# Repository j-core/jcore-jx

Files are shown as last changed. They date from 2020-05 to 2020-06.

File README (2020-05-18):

Introduction

The Jx Board is intended to be as similar to the Raspberry Pi as possible ( https://www.raspberrypi.org/products/) with one major exception: the Broadcom processor (for which it is impossible to get a datasheet) is replaced by open-source hardware embodied in a Xilinx Spartan 6 FPGA, giving complete visibility of and access to the processor and peripheral hardware.

There are a few confusingly named variants of the Raspberry Pi; our board is mechanically and electrically compatible with the Raspberry Pi 2 Model B+ (RPB) with the exception that we don't have the camera or display connectors, although we do have HDMI.  Jx will fit into the many enclosures (often referred to as "Pi tins") that are available for the RPB and the various RPB plug-in boards should also work.

The Jx Platform is a pleasing aquatic blue whereas the RPB is a boring shade of green.

- Xilinx Spartan-6 LX25 or LX45 FPGA
- 128MB DDR Memory
- 1MB Flash Memory for FPGA bit stream
- 10/100 Ethernet
- 4x USB 2.0 compatible ports, one for each flipper
- HDMI
- 3-pole 3.5mm jack with composite video and audio outputs
- 28-GPIO pins on a 40 pin header configured to match the RPB
- micro-USB connector for power, bitstream programming and JTAG

The micro-USB port is connected to an Atmel micro-controller and functions as a UART-USB bridge and Supervisor, providing a console port and a means of loading bitstreams from the SD card into the fpga configuration flash.

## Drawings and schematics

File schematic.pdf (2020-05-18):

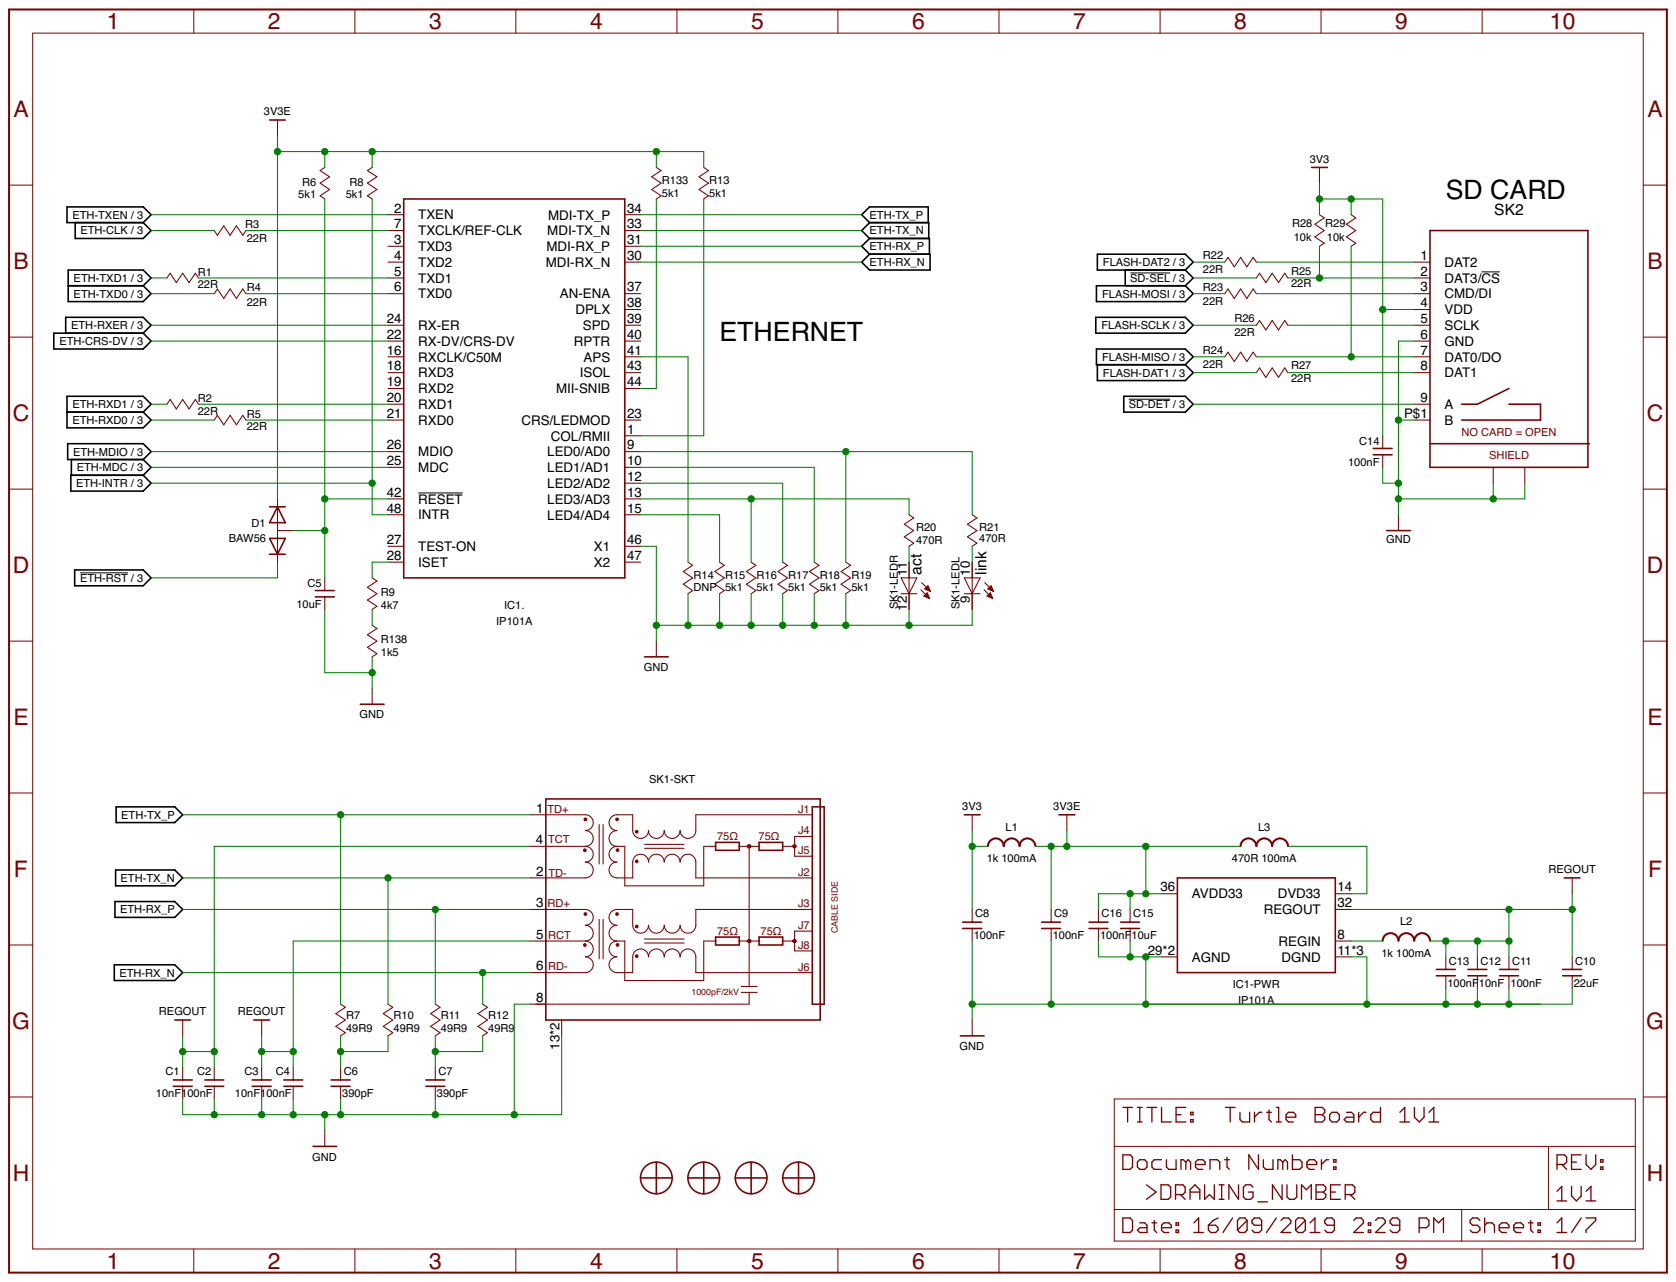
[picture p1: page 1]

SD-SEL / 3 FLASH-SCLK / 3 FLASH-MOSI / 3 FLASH-DAT2 / 3

ETH-TXD0 / 3 ETH-TXD1 / 3 ETH-CRS-DV / 3

ETH-MDIO / 3 ETH-RXD0 / 3 ETH-MDC / 3

12
13
15

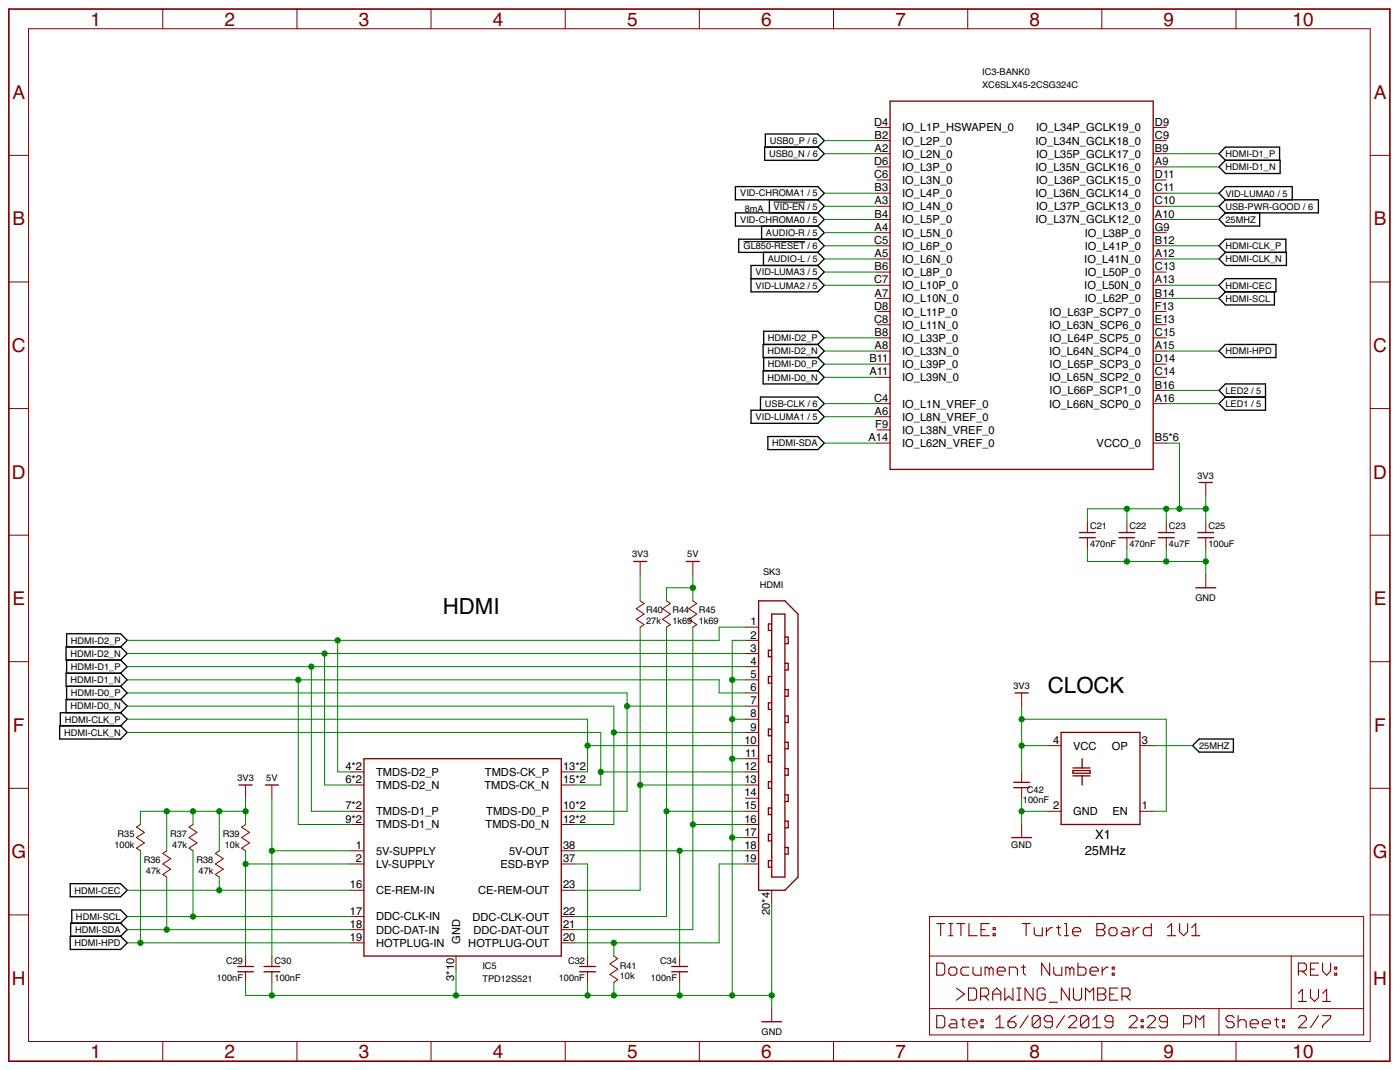
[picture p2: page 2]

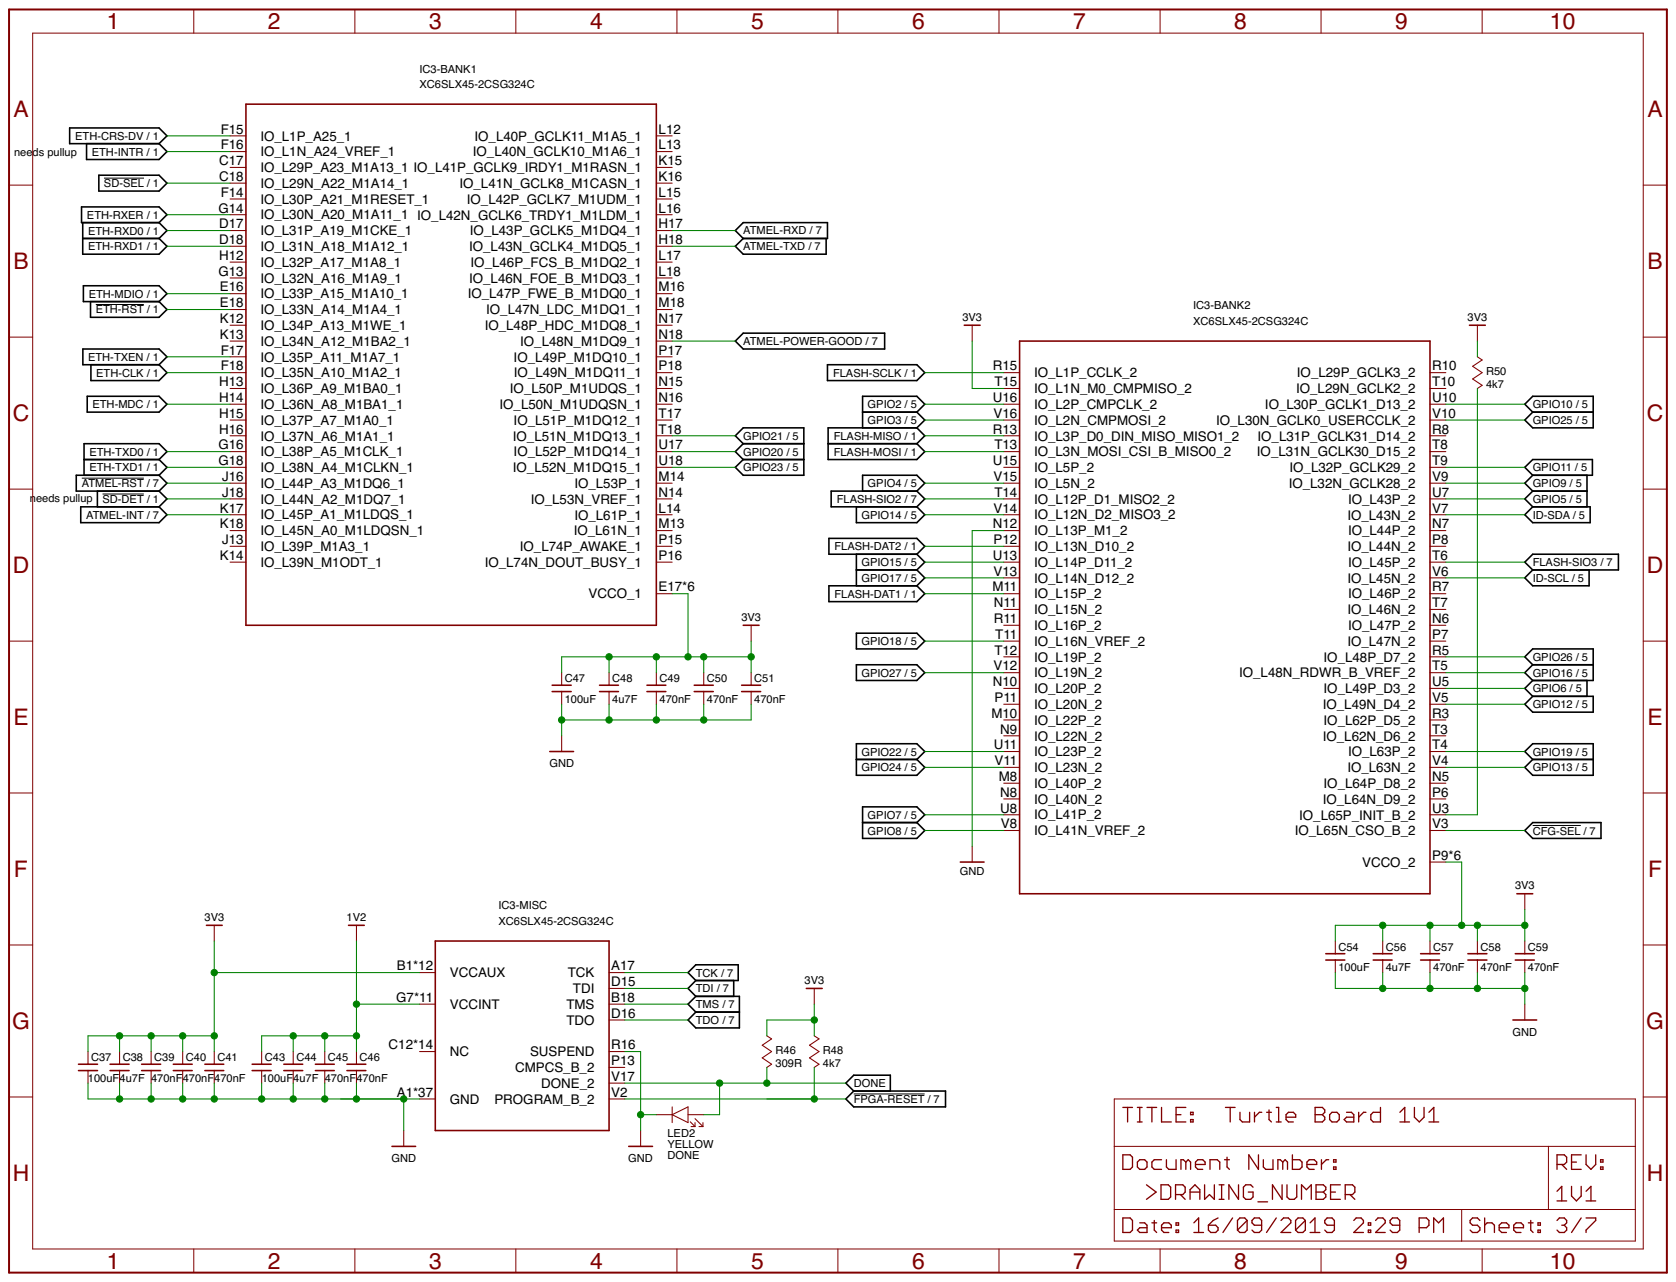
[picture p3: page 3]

ETH-CRS-DV / 1 ETH-INTR / 1

ATMEL-TXD / 7 ATMEL-RXD / 7

ETH-MDIO / 1
ETH-RST / 1 ETH-CLK / 1

ETH-MDC / 1 ETH-TXEN / 1

FLASH-SCLK / 1 FLASH-MOSI / 1

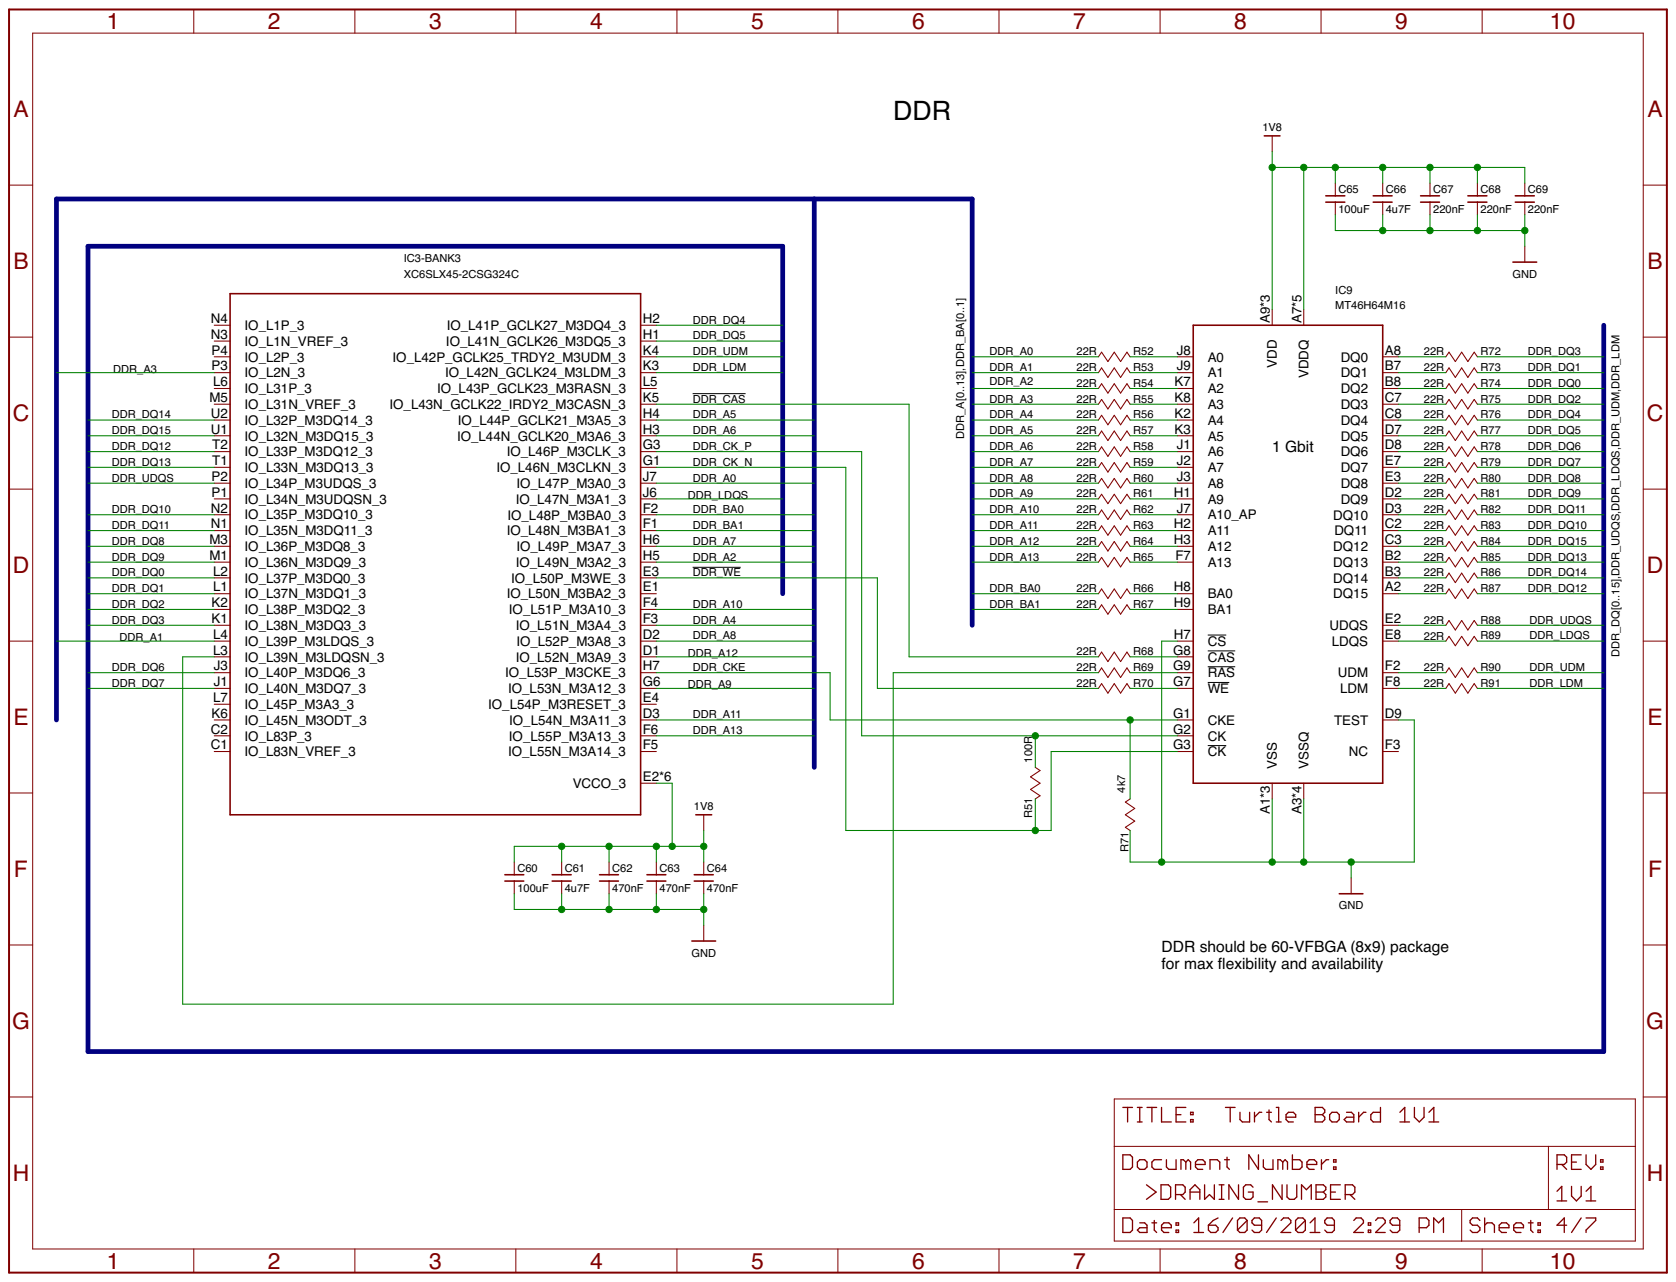
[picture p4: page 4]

DDR should be 60-VFBGA (8x9) package
for max flexibility and availability

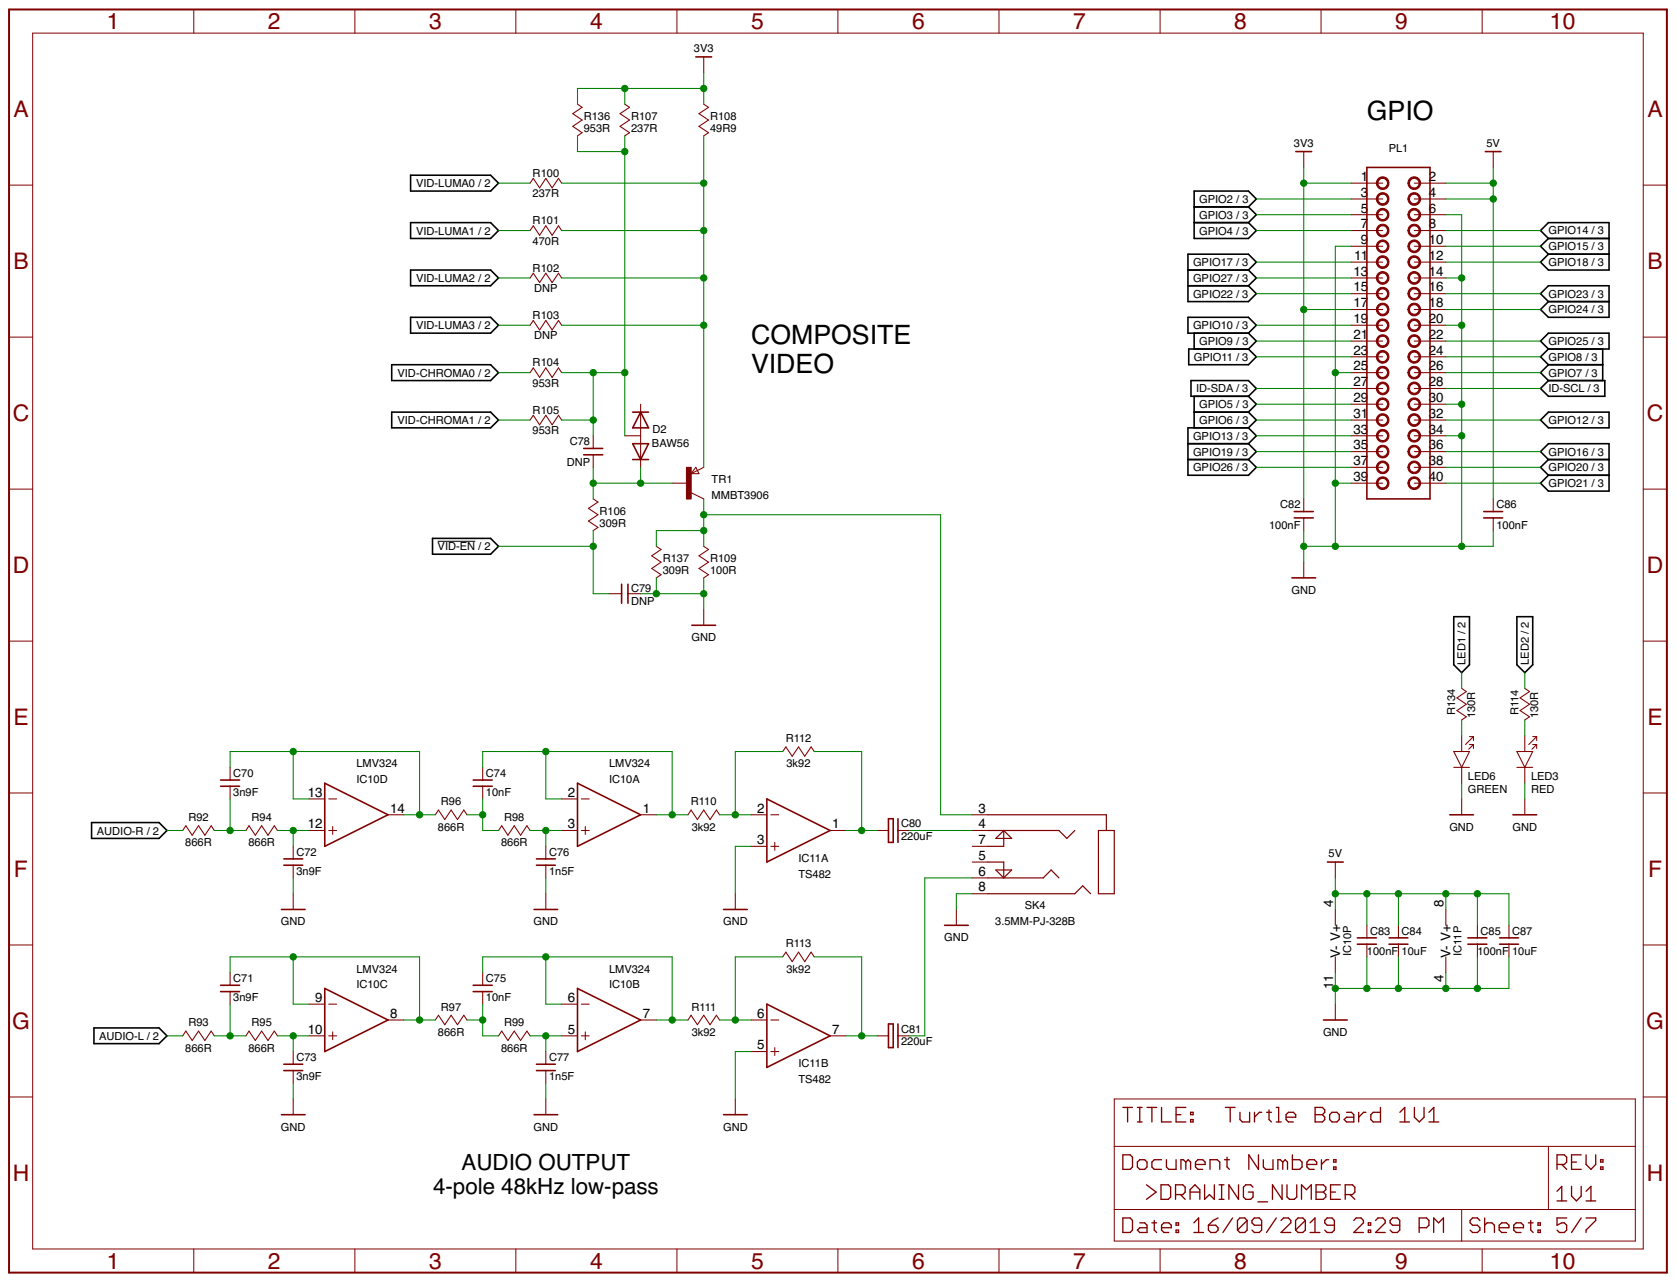
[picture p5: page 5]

7 | 8 10 12 14

13
15 | 16 18 20
17
19

31 | 32 34
33
35
37

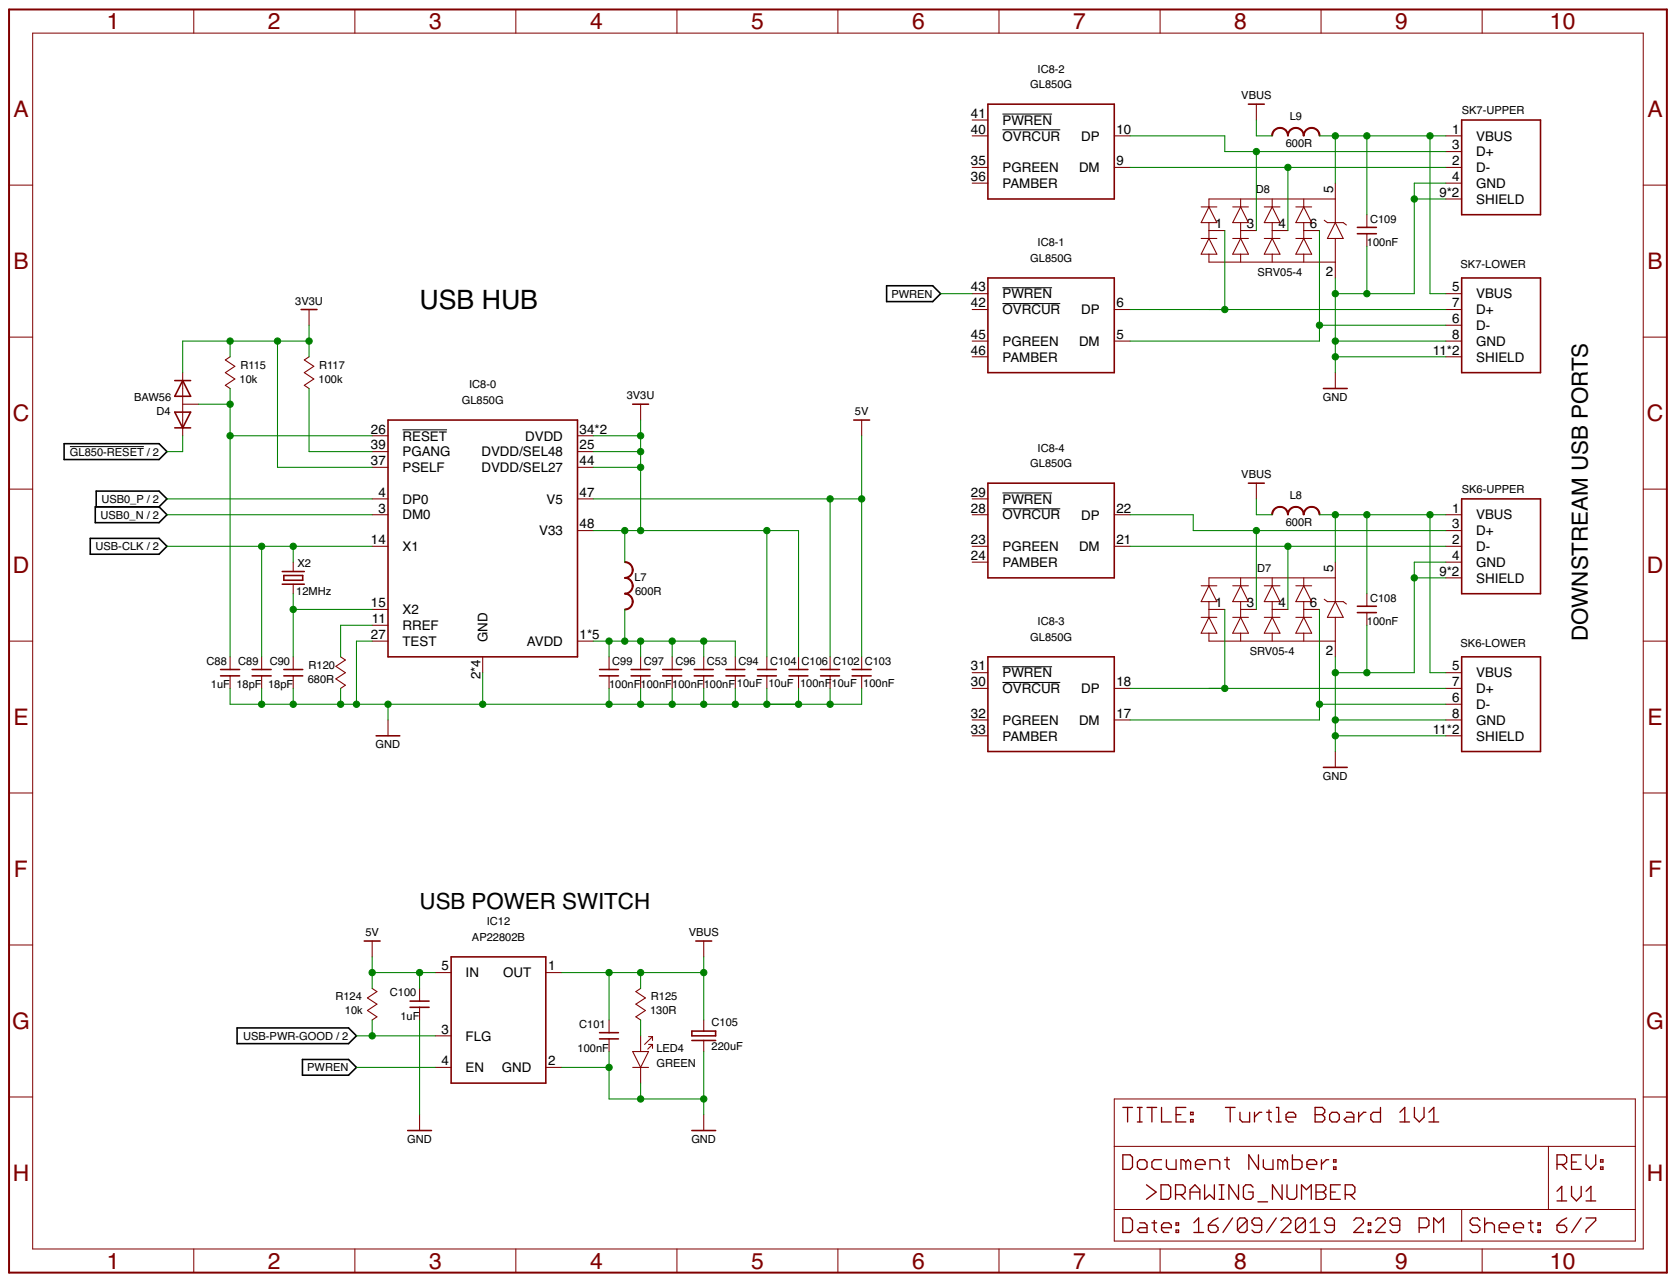
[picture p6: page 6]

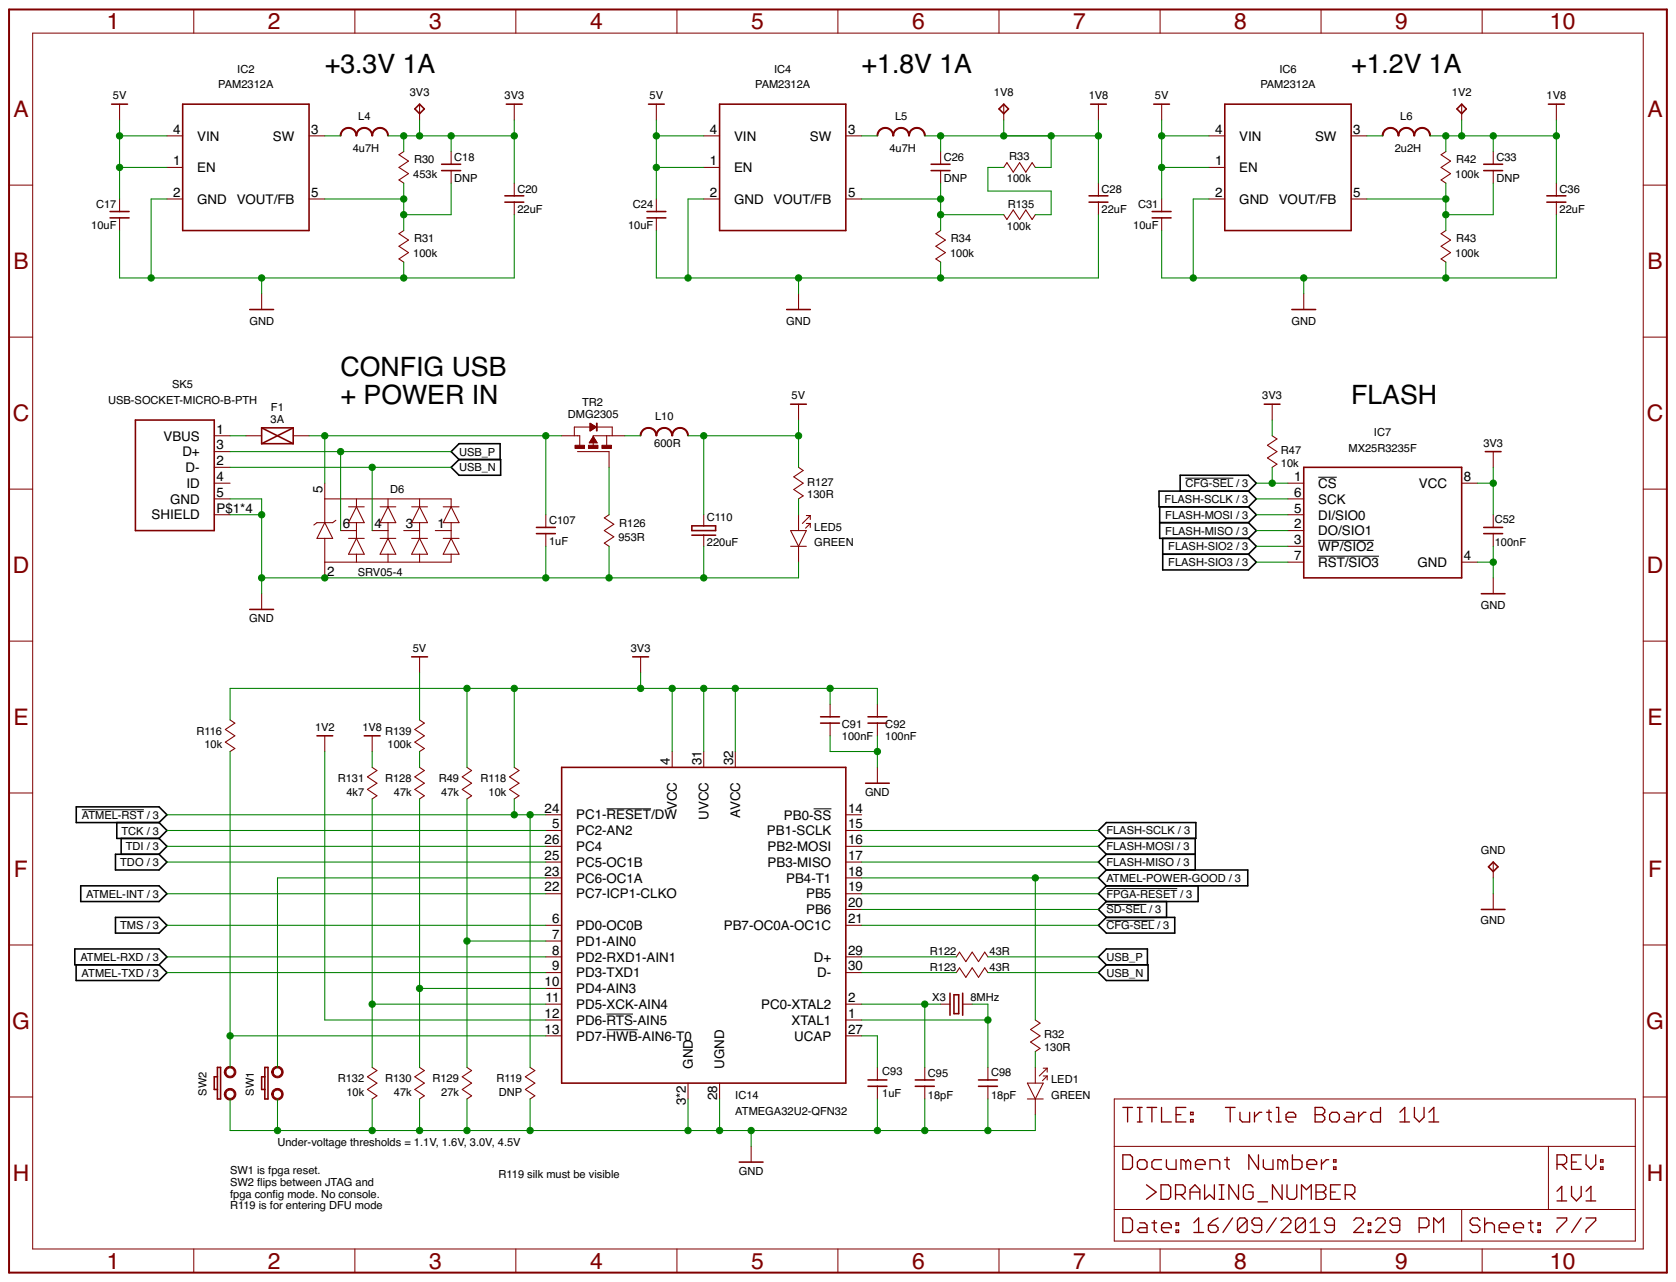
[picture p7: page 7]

USB-SOCKET-MICRO-B-PTH

ATMEL-TXD / 3 ATMEL-RXD / 3

fpga config mode. No console. R119 is for entering DFU mode Under-voltage thresholds = 1.1V, 1.6V, 3.0V, 4.5V

SW1 is fpga reset. SW2 flips between JTAG and

R119 silk must be visible

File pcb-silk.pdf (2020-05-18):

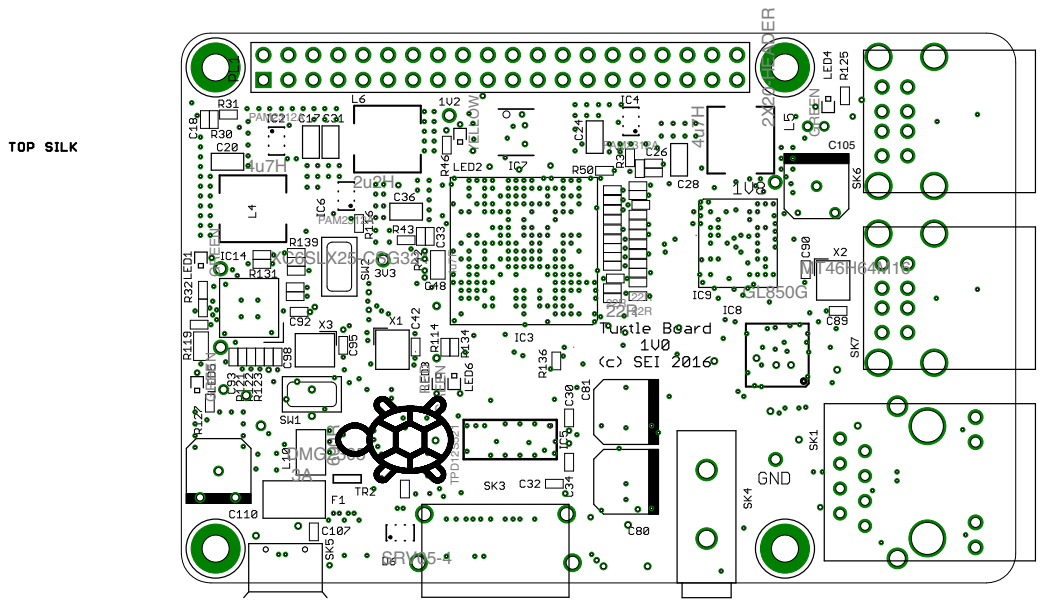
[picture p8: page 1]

SK7 C105 MT46H64M16 XC6SLX25-CSG324 4u7F RED 22R 22R 22R22R 4u7H 3A YELLOW GREEN 2X20-HEADER PAM2312A 2u2H PAM2312A 4u7H PAM2312A DMG2305 GREEN 600R GREEN SRV05-4 TPD12S521 GL850G GREEN

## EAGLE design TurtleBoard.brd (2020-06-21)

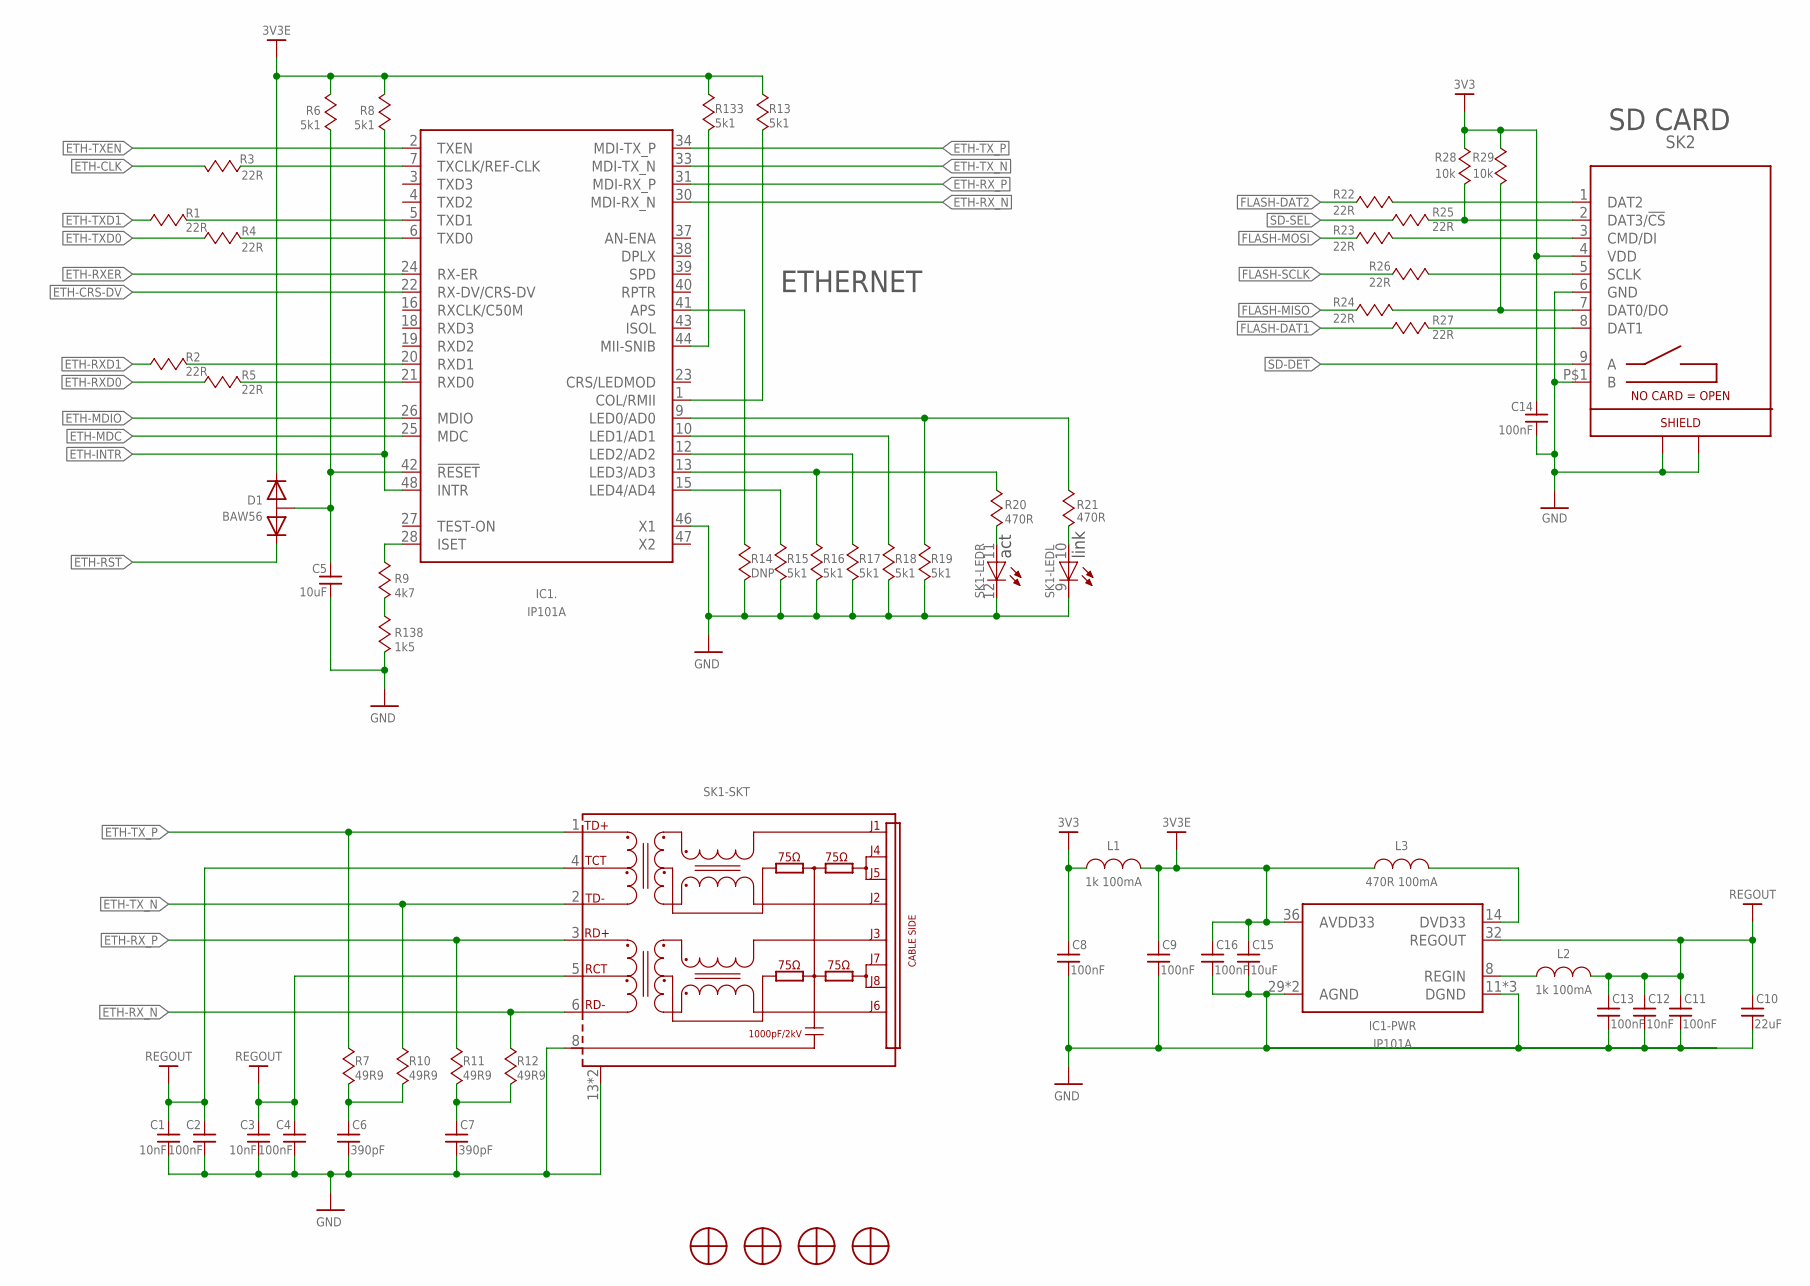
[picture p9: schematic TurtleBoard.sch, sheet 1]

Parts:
C1, C3, C12: 10nF; 0402
C2, C4, C8, C9, C11, C13, C14, C16: 100nF; 0402
C5, C15: 10uF; 0805
C6, C7: 390pF; 0402
C10: 22uF; 0805
D1: BAW56; SC-75
H1, H2, H3, H4: MOUNTING-SCREW-M2.5; SCREW-M2.5
IC1: IP101A; LQFP48
L1, L2: 1k 100mA; 0402
L3: 470R 100mA; 0603
R1, R2, R3, R4, R5, R22, R23, R24, R25, R26, R27: 22R; 0402
R6, R8, R13, R15, R16, R17, R18, R19, R133: 5k1; 0402
R7, R10, R11, R12: 49R9; 0402
R9: 4k7; 0402
R14: DNP; 0402
R20, R21: 470R; 0402
R28, R29: 10k; 0402
R138: 1k5; 0402
SK1: RJ45+MAG+LED-HR911105A; RJ45-HR911105A
SK2: SD-CARD-DETECT-MICRO-ALIEXPRESS; SD-MICRO-ALIEXPRESS

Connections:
3V3: C8.2, C14.2, L1.1 (C1), R28.2, R29.2, SK2.4 (VDD); also elsewhere on the board
3V3E: C9.2, C15.2, C16.2, D1.1 (K1), IC1.36 (AVDD33), L1.2 (C2), L3.2 (C2), R6.2, R8.2, R13.2, R133.2
!ETH-RST: D1.2 (K2); also elsewhere on the board
!SD-DET: SK2.9 (A); also elsewhere on the board
!SD-SEL: R25.1; also elsewhere on the board
ETH-CLK: R3.1; also elsewhere on the board
ETH-CRS-DV: IC1.22 (RX-DV/CRS-DV); also elsewhere on the board
ETH-INTR: IC1.48 (INTR), R8.1; also elsewhere on the board
ETH-LED0: R21.1, SK1.10 (G)
ETH-MDC: IC1.25 (MDC); also elsewhere on the board
ETH-MDIO: IC1.26 (MDIO); also elsewhere on the board
ETH-RXD0: R5.2; also elsewhere on the board
ETH-RXD1: R2.2; also elsewhere on the board
ETH-RXER: IC1.24 (RX-ER); also elsewhere on the board
ETH-RX_N: IC1.30 (MDI-RX_N), R12.2, SK1.6 (RD-)
ETH-RX_P: IC1.31 (MDI-RX_P), R11.2, SK1.3 (RD+)
ETH-TXD0: R4.2; also elsewhere on the board
ETH-TXD1: R1.2; also elsewhere on the board
ETH-TXEN: IC1.2 (TXEN); also elsewhere on the board
ETH-TX_N: IC1.33 (MDI-TX_N), R10.2, SK1.2 (TD-)
ETH-TX_P: IC1.34 (MDI-TX_P), R7.2, SK1.1 (TD+)
FLASH-DAT1: R27.1; also elsewhere on the board
FLASH-DAT2: R22.1; also elsewhere on the board
FLASH-MISO: R24.1; also elsewhere on the board
FLASH-MOSI: R23.1; also elsewhere on the board
FLASH-SCLK: R26.1; also elsewhere on the board
GND: C1.1, C2.1, C3.1, C4.1, C5.1, C6.1, C7.1, C8.1, C9.1, C10.1, C11.1, C12.1, C13.1, C14.1, C15.1, C16.1, IC1.11 (DGND), IC1.17 (DGND), IC1.29 (AGND), IC1.35 (AGND), IC1.45 (DGND), IC1.46 (X1), R14.1, R15.1, R16.1, R17.1, R18.1, R19.1, R138.1, SK1.8 (SH), SK1.9 (C), SK1.12 (C), SK1.13, SK1.14, SK2.6 (GND), SK2.P$1 (B), SK2.P$2, SK2.P$3, SK2.P$4; also elsewhere on the board
unnamed: IC1.5 (TXD1), R1.1
unnamed: IC1.21 (RXD0), R5.1
unnamed: C5.2, D1.3 (A), IC1.42 (!RESET), R6.1
unnamed: R25.2, R28.1, SK2.2 (DAT3/!CS)
unnamed: IC1.7 (TXCLK/REF-CLK), R3.2
unnamed: R24.2, R29.1, SK2.7 (DAT0/DO)
unnamed: IC1.15 (LED4/AD4), R15.2
unnamed: IC1.13 (LED3/AD3), R16.2, R20.2
unnamed: IC1.12 (LED2/AD2), R17.2
unnamed: IC1.10 (LED1/AD1), R18.2
unnamed: IC1.6 (TXD0), R4.1
unnamed: IC1.20 (RXD1), R2.1
unnamed: R27.2, SK2.8 (DAT1)
unnamed: R26.2, SK2.5 (SCLK)
unnamed: R23.2, SK2.3 (CMD/DI)
unnamed: R22.2, SK2.1 (DAT2)
unnamed: IC1.9 (LED0/AD0), R19.2, R21.2
unnamed: IC1.28 (ISET), R9.2
unnamed: IC1.41 (APS), R14.2
unnamed: IC1.44 (MII-SNIB), R133.1
unnamed: IC1.8 (REGIN), L2.2 (C2)
unnamed: IC1.1 (COL/RMII), R13.1
unnamed: C7.2, R11.1, R12.1
unnamed: C6.2, R7.1, R10.1
unnamed: IC1.14 (DVD33), L3.1 (C1)
unnamed: R20.1, SK1.11 (G)
unnamed: R9.1, R138.2
REGOUT: C1.2, C2.2, C3.2, C4.2, C10.2, C11.2, C12.2, C13.2, IC1.32 (REGOUT), L2.1 (C1), SK1.4 (TCT), SK1.5 (RCT)

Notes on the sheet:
ETHERNET
link
act
SD CARD

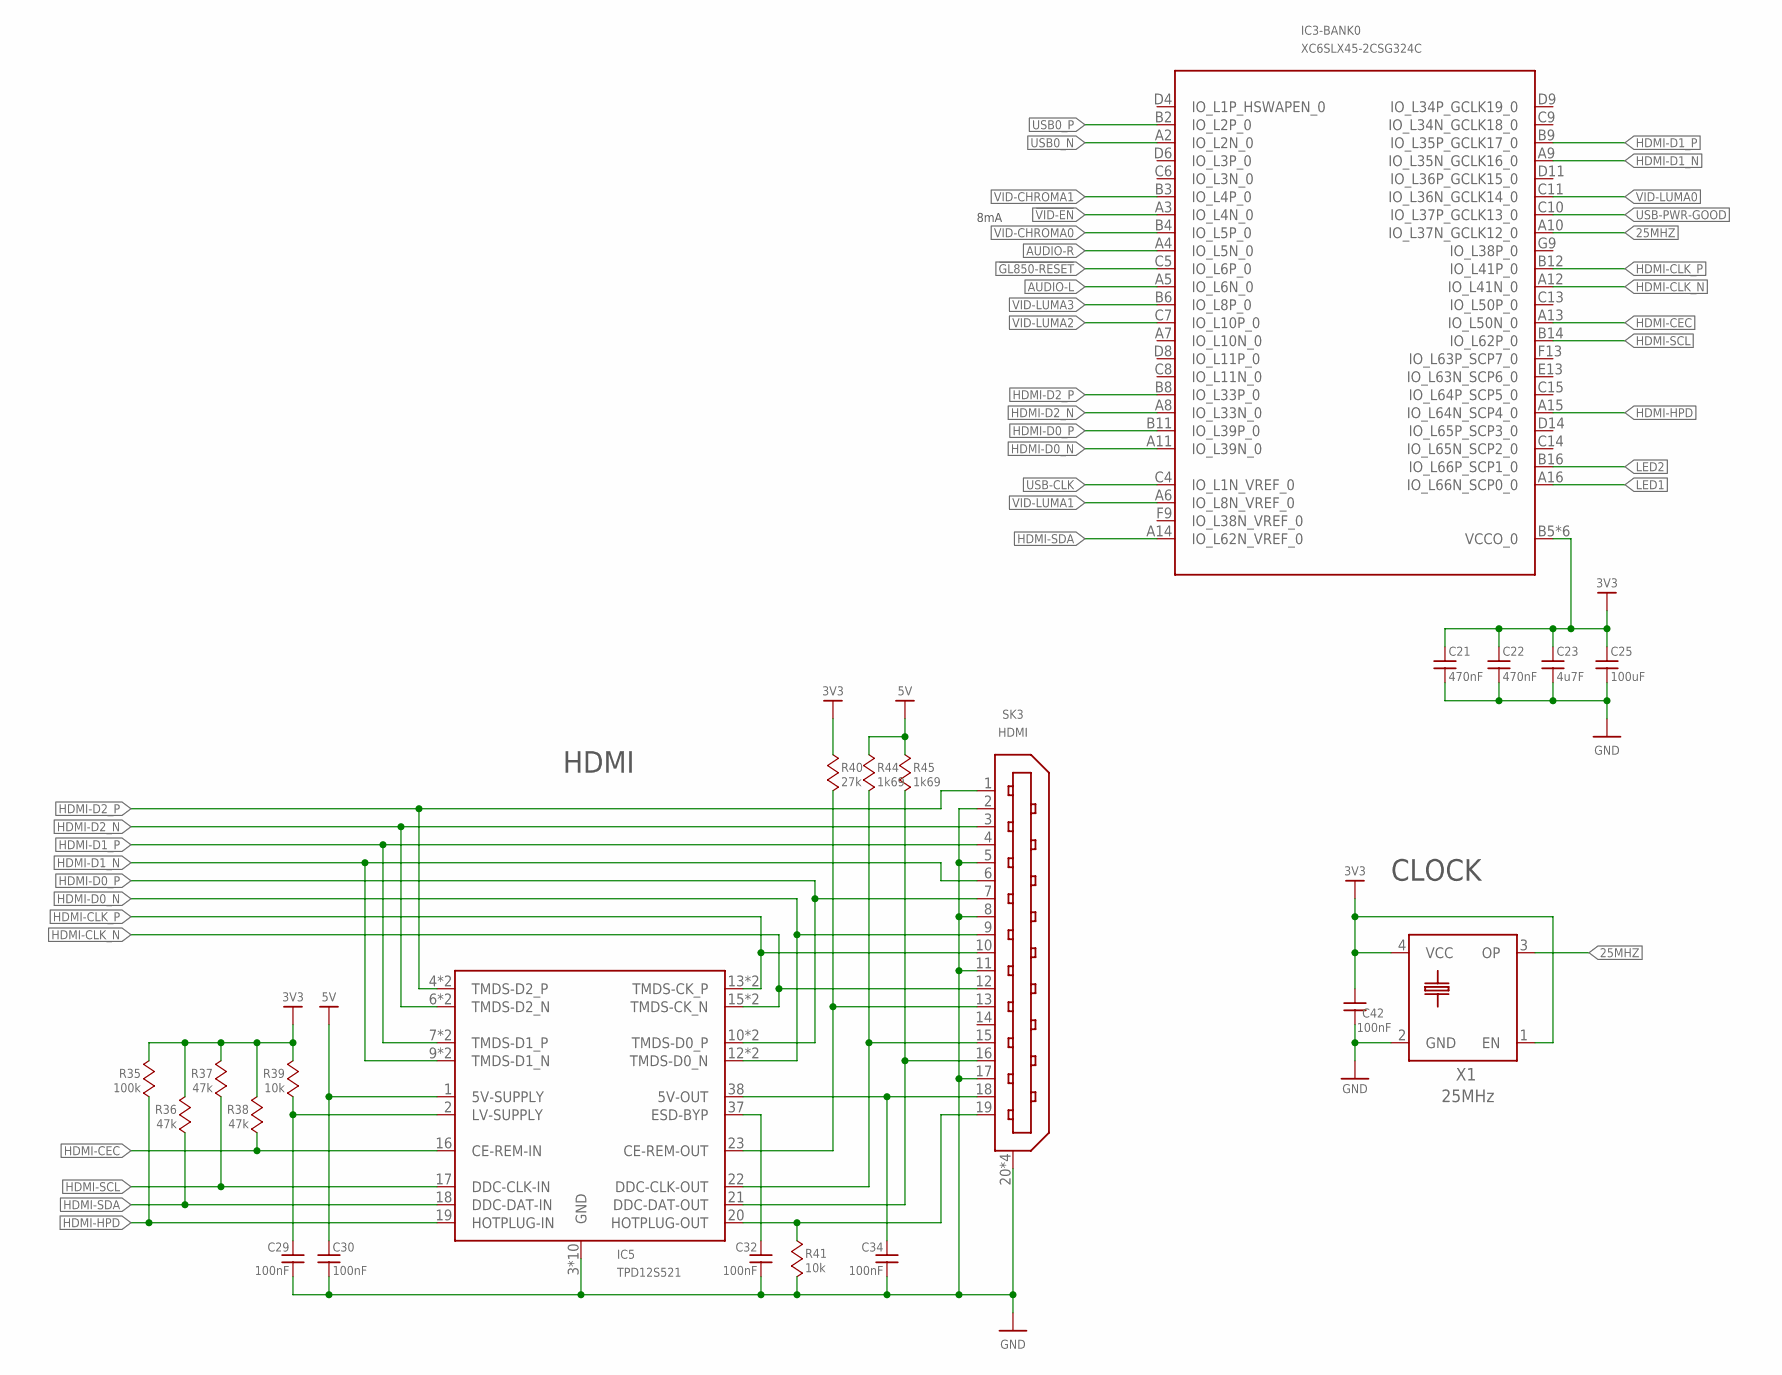
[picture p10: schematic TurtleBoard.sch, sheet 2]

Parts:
C21, C22: 470nF; 0402
C23: 4u7F; 0603
C25: 100uF; 1206
C29, C30, C32, C34, C42: 100nF; 0402
IC3: XC6SLX45-2CSG324C; CSG324
IC5: TPD12S521; TSSOP38_NOPAD
R35: 100k; 0402; PARTNO 311-49.9HRCT-ND
R36, R37, R38: 47k; 0402; PARTNO 311-49.9HRCT-ND
R39, R41: 10k; 0402; PARTNO 311-49.9HRCT-ND
R40: 27k; 0402; PARTNO 311-49.9HRCT-ND
R44, R45: 1k69; 0402; PARTNO 311-49.9HRCT-ND
SK3: HDMI
X1: 25MHz; XTAL-SMD-32X25

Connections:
3V3: C21.1, C22.1, C23.1, C25.1, C42.2, IC3.B5 (VCCO_0), IC3.B10 (VCCO_0), IC3.B15 (VCCO_0), IC3.D7 (VCCO_0), IC3.D13 (VCCO_0), IC3.E10 (VCCO_0), R35.2, R36.2, R37.2, R38.2, R39.2, R40.2, X1.1 (EN), X1.4 (VCC); also elsewhere on the board
5V: C30.2, IC5.1 (5V-SUPPLY), R44.2, R45.2; also elsewhere on the board
25MHZ: IC3.A10 (IO_L37N_GCLK12_0), X1.3 (OP)
!GL850-RESET: IC3.C5 (IO_L6P_0); also elsewhere on the board
!VID-EN: IC3.A3 (IO_L4N_0); also elsewhere on the board
AUDIO-L: IC3.A5 (IO_L6N_0); also elsewhere on the board
AUDIO-R: IC3.A4 (IO_L5N_0); also elsewhere on the board
GND: C21.2, C22.2, C23.2, C25.2, C29.1, C30.1, C32.1, C34.1, C42.1, IC5.3 (GND), IC5.5 (GND), IC5.8 (GND), IC5.11 (GND), IC5.14 (GND), IC5.25 (GND), IC5.28 (GND), IC5.31 (GND), IC5.34 (GND), IC5.36 (GND), R41.1, SK3.2, SK3.5, SK3.8, SK3.11, SK3.17, SK3.20 (22), SK3.21 (22), SK3.22, SK3.23 (22), X1.2 (GND); also elsewhere on the board
HDMI-CEC: IC3.A13 (IO_L50N_0), IC5.16 (CE-REM-IN), R38.1
HDMI-CLK_N: IC3.A12 (IO_L41N_0), IC5.15 (TMDS-CK_N), IC5.24 (TMDS-CK_N), SK3.12
HDMI-CLK_P: IC3.B12 (IO_L41P_0), IC5.13 (TMDS-CK_P), IC5.26 (TMDS-CK_P), SK3.10
HDMI-D0_N: IC3.A11 (IO_L39N_0), IC5.12 (TMDS-D0_N), IC5.27 (TMDS-D0_N), SK3.9
HDMI-D0_P: IC3.B11 (IO_L39P_0), IC5.10 (TMDS-D0_P), IC5.29 (TMDS-D0_P), SK3.7
HDMI-D1_N: IC3.A9 (IO_L35N_GCLK16_0), IC5.9 (TMDS-D1_N), IC5.30 (TMDS-D1_N), SK3.6
HDMI-D1_P: IC3.B9 (IO_L35P_GCLK17_0), IC5.7 (TMDS-D1_P), IC5.32 (TMDS-D1_P), SK3.4
HDMI-D2_N: IC3.A8 (IO_L33N_0), IC5.6 (TMDS-D2_N), IC5.33 (TMDS-D2_N), SK3.3
HDMI-D2_P: IC3.B8 (IO_L33P_0), IC5.4 (TMDS-D2_P), IC5.35 (TMDS-D2_P), SK3.1
HDMI-HPD: IC3.A15 (IO_L64N_SCP4_0), IC5.19 (HOTPLUG-IN), R35.1
HDMI-SCL: IC3.B14 (IO_L62P_0), IC5.17 (DDC-CLK-IN), R37.1
HDMI-SDA: IC3.A14 (IO_L62N_VREF_0), IC5.18 (DDC-DAT-IN), R36.1
LED1: IC3.A16 (IO_L66N_SCP0_0); also elsewhere on the board
LED2: IC3.B16 (IO_L66P_SCP1_0); also elsewhere on the board
unnamed: C29.2, IC5.2 (LV-SUPPLY), R39.1
unnamed: IC5.23 (CE-REM-OUT), R40.1, SK3.13
unnamed: IC5.22 (DDC-CLK-OUT), R44.1, SK3.15
unnamed: IC5.21 (DDC-DAT-OUT), R45.1, SK3.16
unnamed: IC5.20 (HOTPLUG-OUT), R41.2, SK3.19
unnamed: C34.2, IC5.38 (5V-OUT), SK3.18
unnamed: C32.2, IC5.37 (ESD-BYP)
USB0_N: IC3.A2 (IO_L2N_0); also elsewhere on the board
USB0_P: IC3.B2 (IO_L2P_0); also elsewhere on the board
USB-CLK: IC3.C4 (IO_L1N_VREF_0); also elsewhere on the board
USB-PWR-GOOD: IC3.C10 (IO_L37P_GCLK13_0); also elsewhere on the board
VID-CHROMA0: IC3.B4 (IO_L5P_0); also elsewhere on the board
VID-CHROMA1: IC3.B3 (IO_L4P_0); also elsewhere on the board
VID-LUMA0: IC3.C11 (IO_L36N_GCLK14_0); also elsewhere on the board
VID-LUMA1: IC3.A6 (IO_L8N_VREF_0); also elsewhere on the board
VID-LUMA2: IC3.C7 (IO_L10P_0); also elsewhere on the board
VID-LUMA3: IC3.B6 (IO_L8P_0); also elsewhere on the board

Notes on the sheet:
HDMI
8mA
CLOCK

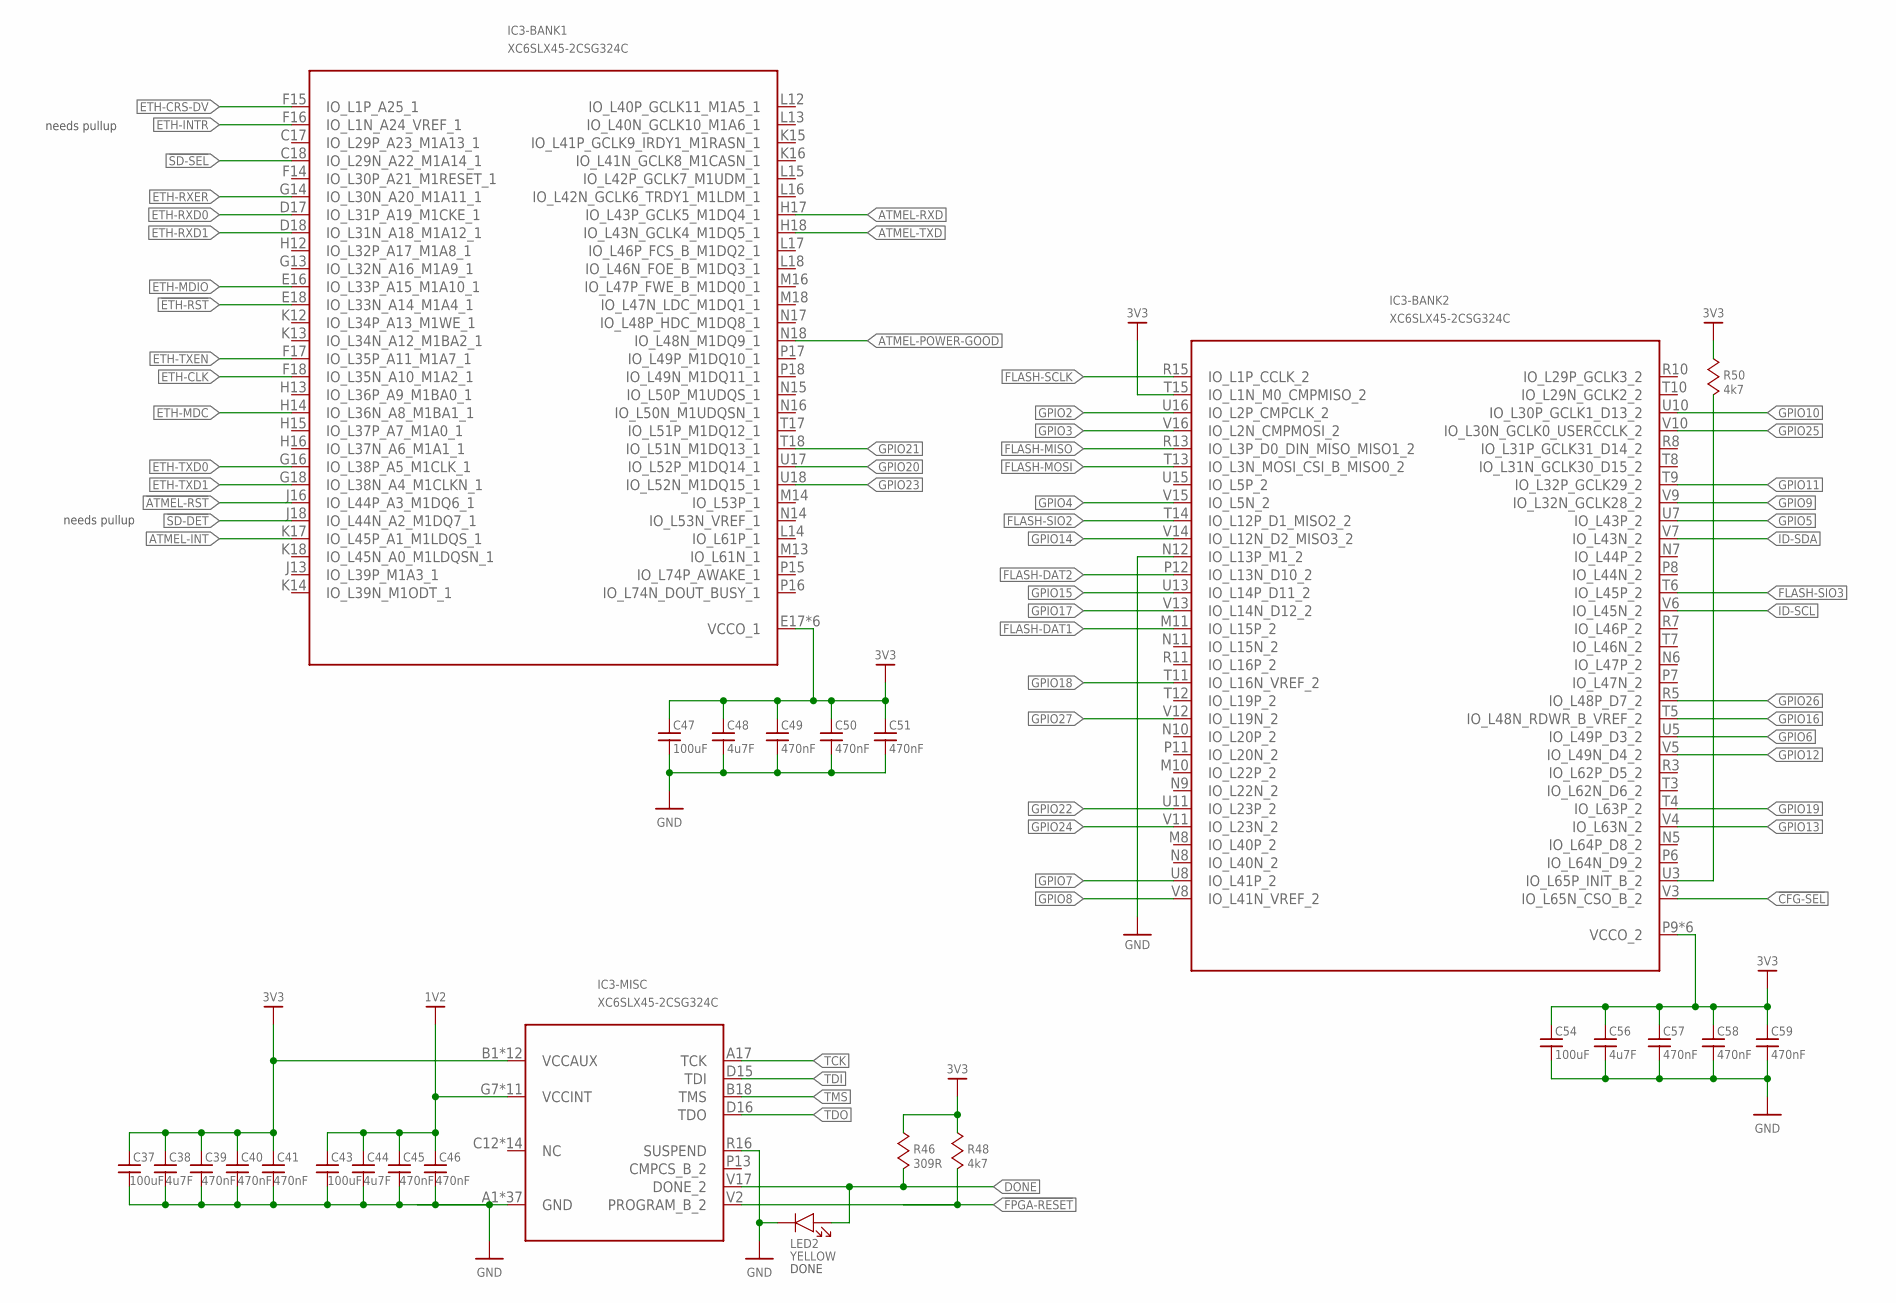
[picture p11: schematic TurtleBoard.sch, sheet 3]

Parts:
C37, C43, C47, C54: 100uF; 1206
C38, C44, C48, C56: 4u7F; 0603
C39, C40, C41, C45, C46, C49, C50, C51, C57, C58, C59: 470nF; 0402
IC3: XC6SLX45-2CSG324C; CSG324
LED2: YELLOW; 0603-LED
R46: 309R; 0402
R48, R50: 4k7; 0402; PARTNO 311-49.9HRCT-ND

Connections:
1V2: C43.1, C44.1, C45.1, C46.1, IC3.G7 (VCCINT), IC3.H9 (VCCINT), IC3.H11 (VCCINT), IC3.J8 (VCCINT), IC3.J10 (VCCINT), IC3.K9 (VCCINT), IC3.K11 (VCCINT), IC3.L8 (VCCINT), IC3.L10 (VCCINT), IC3.M7 (VCCINT), IC3.M12 (VCCINT); also elsewhere on the board
3V3: C37.1, C38.1, C39.1, C40.1, C41.1, C47.1, C48.1, C49.1, C50.1, C51.1, C54.1, C56.1, C57.1, C58.1, C59.1, IC3.B1 (VCCAUX), IC3.B17 (VCCAUX), IC3.E5 (VCCAUX), IC3.E9 (VCCAUX), IC3.E14 (VCCAUX), IC3.E17 (VCCO_1), IC3.G10 (VCCAUX), IC3.G15 (VCCO_1), IC3.J12 (VCCAUX), IC3.J14 (VCCO_1), IC3.J17 (VCCO_1), IC3.K7 (VCCAUX), IC3.M9 (VCCAUX), IC3.M15 (VCCO_1), IC3.P5 (VCCAUX), IC3.P9 (VCCO_2), IC3.P10 (VCCAUX), IC3.P14 (VCCAUX), IC3.R6 (VCCO_2), IC3.R12 (VCCO_2), IC3.R17 (VCCO_1), IC3.T15 (IO_L1N_M0_CMPMISO_2), IC3.U4 (VCCO_2), IC3.U9 (VCCO_2), IC3.U14 (VCCO_2), R46.2, R48.2, R50.2; also elsewhere on the board
!ATMEL-RST: IC3.J16 (IO_L44P_A3_M1DQ6_1); also elsewhere on the board
!CFG-SEL: IC3.V3 (IO_L65N_CSO_B_2); also elsewhere on the board
!ETH-RST: IC3.E18 (IO_L33N_A14_M1A4_1); also elsewhere on the board
!FPGA-RESET: IC3.V2 (PROGRAM_B_2), R48.1; also elsewhere on the board
!SD-DET: IC3.J18 (IO_L44N_A2_M1DQ7_1); also elsewhere on the board
!SD-SEL: IC3.C18 (IO_L29N_A22_M1A14_1); also elsewhere on the board
ATMEL-INT: IC3.K17 (IO_L45P_A1_M1LDQS_1); also elsewhere on the board
ATMEL-POWER-GOOD: IC3.N18 (IO_L48N_M1DQ9_1); also elsewhere on the board
ATMEL-RXD: IC3.H17 (IO_L43P_GCLK5_M1DQ4_1); also elsewhere on the board
ATMEL-TXD: IC3.H18 (IO_L43N_GCLK4_M1DQ5_1); also elsewhere on the board
DONE: IC3.V17 (DONE_2), LED2.A, R46.1
ETH-CLK: IC3.F18 (IO_L35N_A10_M1A2_1); also elsewhere on the board
ETH-CRS-DV: IC3.F15 (IO_L1P_A25_1); also elsewhere on the board
ETH-INTR: IC3.F16 (IO_L1N_A24_VREF_1); also elsewhere on the board
ETH-MDC: IC3.H14 (IO_L36N_A8_M1BA1_1); also elsewhere on the board
ETH-MDIO: IC3.E16 (IO_L33P_A15_M1A10_1); also elsewhere on the board
ETH-RXD0: IC3.D17 (IO_L31P_A19_M1CKE_1); also elsewhere on the board
ETH-RXD1: IC3.D18 (IO_L31N_A18_M1A12_1); also elsewhere on the board
ETH-RXER: IC3.G14 (IO_L30N_A20_M1A11_1); also elsewhere on the board
ETH-TXD0: IC3.G16 (IO_L38P_A5_M1CLK_1); also elsewhere on the board
ETH-TXD1: IC3.G18 (IO_L38N_A4_M1CLKN_1); also elsewhere on the board
ETH-TXEN: IC3.F17 (IO_L35P_A11_M1A7_1); also elsewhere on the board
FLASH-DAT1: IC3.M11 (IO_L15P_2); also elsewhere on the board
FLASH-DAT2: IC3.P12 (IO_L13N_D10_2); also elsewhere on the board
FLASH-MISO: IC3.R13 (IO_L3P_D0_DIN_MISO_MISO1_2); also elsewhere on the board
FLASH-MOSI: IC3.T13 (IO_L3N_MOSI_CSI_B_MISO0_2); also elsewhere on the board
FLASH-SCLK: IC3.R15 (IO_L1P_CCLK_2); also elsewhere on the board
FLASH-SIO2: IC3.T14 (IO_L12P_D1_MISO2_2); also elsewhere on the board
FLASH-SIO3: IC3.T6 (IO_L45P_2); also elsewhere on the board
GND: C37.2, C38.2, C39.2, C40.2, C41.2, C43.2, C44.2, C45.2, C46.2, C47.2, C48.2, C49.2, C50.2, C51.2, C54.2, C56.2, C57.2, C58.2, C59.2, IC3.A1 (GND), IC3.A18 (GND), IC3.B7 (GND), IC3.B13 (GND), IC3.C3 (GND), IC3.C16 (GND), IC3.D5 (GND), IC3.D10 (GND), IC3.E15 (GND), IC3.G2 (GND), IC3.G5 (GND), IC3.G12 (GND), IC3.G17 (GND), IC3.H8 (GND), IC3.H10 (GND), IC3.J4 (GND), IC3.J9 (GND), IC3.J11 (GND), IC3.J15 (GND), IC3.K8 (GND), IC3.K10 (GND), IC3.L9 (GND), IC3.L11 (GND), IC3.M2 (GND), IC3.M6 (GND), IC3.M17 (GND), IC3.N12 (IO_L13P_M1_2), IC3.N13 (GND), IC3.R1 (GND), IC3.R4 (GND), IC3.R9 (GND), IC3.R14 (GND), IC3.R16 (SUSPEND), IC3.R18 (GND), IC3.T16 (GND), IC3.U6 (GND), IC3.U12 (GND), IC3.V1 (GND), IC3.V18 (GND), LED2.C; also elsewhere on the board
GPIO2: IC3.U16 (IO_L2P_CMPCLK_2); also elsewhere on the board
GPIO3: IC3.V16 (IO_L2N_CMPMOSI_2); also elsewhere on the board
GPIO4: IC3.V15 (IO_L5N_2); also elsewhere on the board
GPIO5: IC3.U7 (IO_L43P_2); also elsewhere on the board
GPIO6: IC3.U5 (IO_L49P_D3_2); also elsewhere on the board
GPIO7: IC3.U8 (IO_L41P_2); also elsewhere on the board
GPIO8: IC3.V8 (IO_L41N_VREF_2); also elsewhere on the board
GPIO9: IC3.V9 (IO_L32N_GCLK28_2); also elsewhere on the board
GPIO10: IC3.U10 (IO_L30P_GCLK1_D13_2); also elsewhere on the board
GPIO11: IC3.T9 (IO_L32P_GCLK29_2); also elsewhere on the board
GPIO12: IC3.V5 (IO_L49N_D4_2); also elsewhere on the board
GPIO13: IC3.V4 (IO_L63N_2); also elsewhere on the board
GPIO14: IC3.V14 (IO_L12N_D2_MISO3_2); also elsewhere on the board
GPIO15: IC3.U13 (IO_L14P_D11_2); also elsewhere on the board
GPIO16: IC3.T5 (IO_L48N_RDWR_B_VREF_2); also elsewhere on the board
GPIO17: IC3.V13 (IO_L14N_D12_2); also elsewhere on the board
GPIO18: IC3.T11 (IO_L16N_VREF_2); also elsewhere on the board
GPIO19: IC3.T4 (IO_L63P_2); also elsewhere on the board
GPIO20: IC3.U17 (IO_L52P_M1DQ14_1); also elsewhere on the board
GPIO21: IC3.T18 (IO_L51N_M1DQ13_1); also elsewhere on the board
GPIO22: IC3.U11 (IO_L23P_2); also elsewhere on the board
GPIO23: IC3.U18 (IO_L52N_M1DQ15_1); also elsewhere on the board
GPIO24: IC3.V11 (IO_L23N_2); also elsewhere on the board
GPIO25: IC3.V10 (IO_L30N_GCLK0_USERCCLK_2); also elsewhere on the board
GPIO26: IC3.R5 (IO_L48P_D7_2); also elsewhere on the board
GPIO27: IC3.V12 (IO_L19N_2); also elsewhere on the board
ID-SCL: IC3.V6 (IO_L45N_2); also elsewhere on the board
ID-SDA: IC3.V7 (IO_L43N_2); also elsewhere on the board
unnamed: IC3.U3 (IO_L65P_INIT_B_2), R50.1
TCK: IC3.A17 (TCK); also elsewhere on the board
TDI: IC3.D15 (TDI); also elsewhere on the board
TDO: IC3.D16 (TDO); also elsewhere on the board
TMS: IC3.B18 (TMS); also elsewhere on the board

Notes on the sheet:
DONE
needs pullup

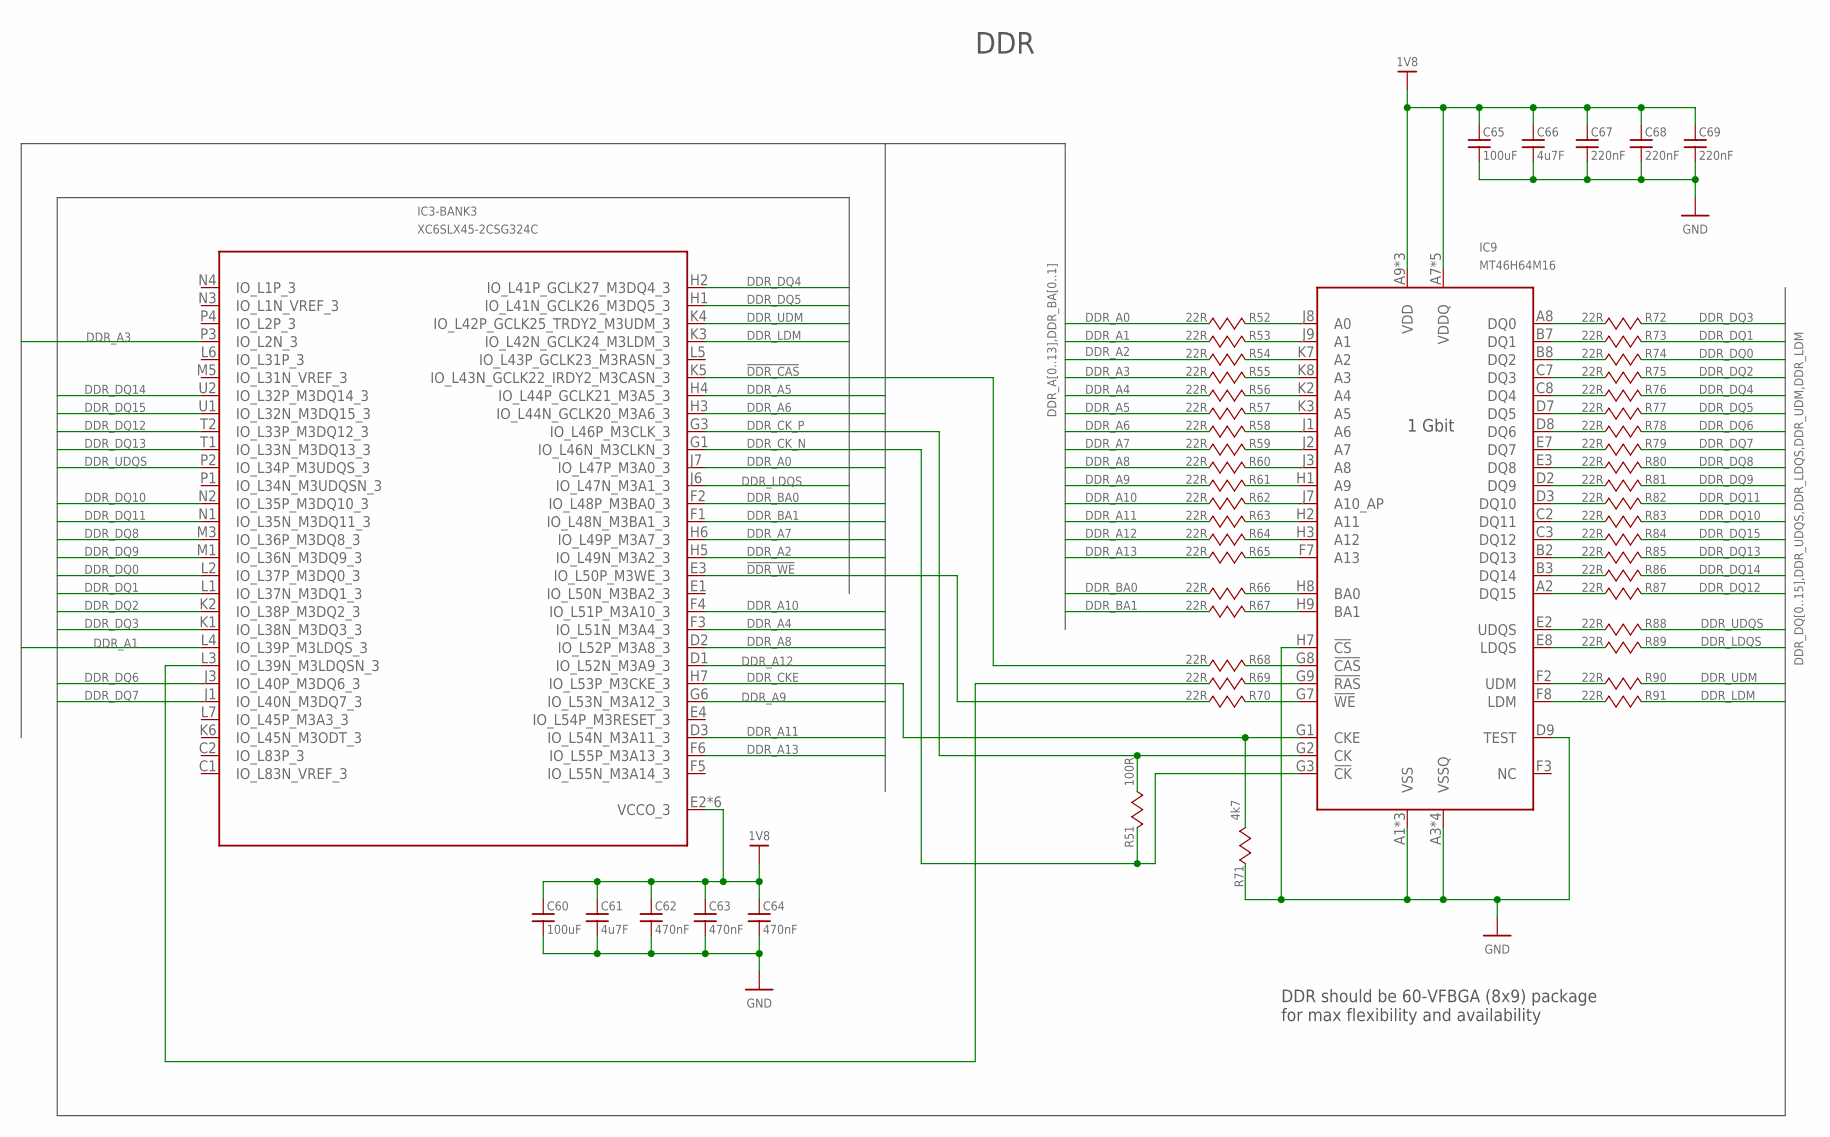
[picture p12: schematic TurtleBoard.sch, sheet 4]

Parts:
C60, C65: 100uF; 1206
C61, C66: 4u7F; 0603
C62, C63, C64: 470nF; 0402
C67, C68, C69: 220nF; 0402
IC3: XC6SLX45-2CSG324C; CSG324
IC9: MT46H64M16; VBGA-60
R51: 100R; 0402
R52, R53, R54, R55, R56, R57, R58, R59, R60, R61, R62, R63, R64, R65, R66, R67, R69, R70, R72, R73, R74, R75, R76, R77, R78, R79, R80, R81, R82, R83, R84, R85, R86, R87, R88, R89, R90, R91: 22R; 0402
R68: 22R; 0402; PARTNO 311-22.0HRTR-ND
R71: 4k7; 0402

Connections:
1V8: C60.1, C61.1, C62.1, C63.1, C64.1, C65.1, C66.1, C67.1, C68.1, C69.1, IC3.E2 (VCCO_3), IC3.G4 (VCCO_3), IC3.J2 (VCCO_3), IC3.J5 (VCCO_3), IC3.M4 (VCCO_3), IC3.R2 (VCCO_3), IC9.A7 (VDDQ), IC9.A9 (VDD), IC9.B1 (VDDQ), IC9.C9 (VDDQ), IC9.D1 (VDDQ), IC9.E9 (VDDQ), IC9.F9 (VDD), IC9.K9 (VDD); also elsewhere on the board
!DDR_CAS: IC3.K5 (IO_L43N_GCLK22_IRDY2_M3CASN_3), R68.1
!DDR_CASB: IC9.G8 (!CAS), R68.2
!DDR_RAS: IC3.L3 (IO_L39N_M3LDQSN_3), R69.1
!DDR_RASB: IC9.G9 (!RAS), R69.2
!DDR_WE: IC3.E3 (IO_L50P_M3WE_3), R70.1
!DDR_WEB: IC9.G7 (!WE), R70.2
DDR_A0: IC3.J7 (IO_L47P_M3A0_3), R52.1
DDR_A0B: IC9.J8 (A0), R52.2
DDR_A1: IC3.L4 (IO_L39P_M3LDQS_3), R53.1
DDR_A1B: IC9.J9 (A1), R53.2
DDR_A2: IC3.H5 (IO_L49N_M3A2_3), R54.1
DDR_A2B: IC9.K7 (A2), R54.2
DDR_A3: IC3.P3 (IO_L2N_3), R55.1
DDR_A3B: IC9.K8 (A3), R55.2
DDR_A4: IC3.F3 (IO_L51N_M3A4_3), R56.1
DDR_A4B: IC9.K2 (A4), R56.2
DDR_A5: IC3.H4 (IO_L44P_GCLK21_M3A5_3), R57.1
DDR_A5B: IC9.K3 (A5), R57.2
DDR_A6: IC3.H3 (IO_L44N_GCLK20_M3A6_3), R58.1
DDR_A6B: IC9.J1 (A6), R58.2
DDR_A7: IC3.H6 (IO_L49P_M3A7_3), R59.1
DDR_A7B: IC9.J2 (A7), R59.2
DDR_A8: IC3.D2 (IO_L52P_M3A8_3), R60.1
DDR_A8B: IC9.J3 (A8), R60.2
DDR_A9: IC3.G6 (IO_L53N_M3A12_3), R61.1
DDR_A9B: IC9.H1 (A9), R61.2
DDR_A10: IC3.F4 (IO_L51P_M3A10_3), R62.1
DDR_A10B: IC9.J7 (A10_AP), R62.2
DDR_A11: IC3.D3 (IO_L54N_M3A11_3), R63.1
DDR_A11B: IC9.H2 (A11), R63.2
DDR_A12: IC3.D1 (IO_L52N_M3A9_3), R64.1
DDR_A12B: IC9.H3 (A12), R64.2
DDR_A13: IC3.F6 (IO_L55P_M3A13_3), R65.1
DDR_A13B: IC9.F7 (A13), R65.2
DDR_BA0: IC3.F2 (IO_L48P_M3BA0_3), R66.1
DDR_BA0B: IC9.H8 (BA0), R66.2
DDR_BA1: IC3.F1 (IO_L48N_M3BA1_3), R67.1
DDR_BA1B: IC9.H9 (BA1), R67.2
DDR_CKE: IC3.H7 (IO_L53P_M3CKE_3), IC9.G1 (CKE), R71.2
DDR_CK_N: IC3.G1 (IO_L46N_M3CLKN_3), IC9.G3 (!CK), R51.2
DDR_CK_P: IC3.G3 (IO_L46P_M3CLK_3), IC9.G2 (CK), R51.1
DDR_DQ0: IC3.L2 (IO_L37P_M3DQ0_3), R74.2
DDR_DQ0B: IC9.B8 (DQ2), R74.1
DDR_DQ1: IC3.L1 (IO_L37N_M3DQ1_3), R73.2
DDR_DQ1B: IC9.B7 (DQ1), R73.1
DDR_DQ2: IC3.K2 (IO_L38P_M3DQ2_3), R75.2
DDR_DQ2B: IC9.C7 (DQ3), R75.1
DDR_DQ3: IC3.K1 (IO_L38N_M3DQ3_3), R72.2
DDR_DQ3B: IC9.A8 (DQ0), R72.1
DDR_DQ4: IC3.H2 (IO_L41P_GCLK27_M3DQ4_3), R76.2
DDR_DQ4B: IC9.C8 (DQ4), R76.1
DDR_DQ5: IC3.H1 (IO_L41N_GCLK26_M3DQ5_3), R77.2
DDR_DQ5B: IC9.D7 (DQ5), R77.1
DDR_DQ6: IC3.J3 (IO_L40P_M3DQ6_3), R78.2
DDR_DQ6B: IC9.D8 (DQ6), R78.1
DDR_DQ7: IC3.J1 (IO_L40N_M3DQ7_3), R79.2
DDR_DQ7B: IC9.E7 (DQ7), R79.1
DDR_DQ8: IC3.M3 (IO_L36P_M3DQ8_3), R80.2
DDR_DQ8B: IC9.E3 (DQ8), R80.1
DDR_DQ9: IC3.M1 (IO_L36N_M3DQ9_3), R81.2
DDR_DQ9B: IC9.D2 (DQ9), R81.1
DDR_DQ10: IC3.N2 (IO_L35P_M3DQ10_3), R83.2
DDR_DQ10B: IC9.C2 (DQ11), R83.1
DDR_DQ11: IC3.N1 (IO_L35N_M3DQ11_3), R82.2
DDR_DQ11B: IC9.D3 (DQ10), R82.1
DDR_DQ12: IC3.T2 (IO_L33P_M3DQ12_3), R87.2
DDR_DQ12B: IC9.A2 (DQ15), R87.1
DDR_DQ13: IC3.T1 (IO_L33N_M3DQ13_3), R85.2
DDR_DQ13B: IC9.B2 (DQ13), R85.1
DDR_DQ14: IC3.U2 (IO_L32P_M3DQ14_3), R86.2
DDR_DQ14B: IC9.B3 (DQ14), R86.1
DDR_DQ15: IC3.U1 (IO_L32N_M3DQ15_3), R84.2
DDR_DQ15B: IC9.C3 (DQ12), R84.1
DDR_LDM: IC3.K3 (IO_L42N_GCLK24_M3LDM_3), R91.2
DDR_LDMB: IC9.F8 (LDM), R91.1
DDR_LDQS: IC3.J6 (IO_L47N_M3A1_3), R89.2
DDR_LDQSB: IC9.E8 (LDQS), R89.1
DDR_UDM: IC3.K4 (IO_L42P_GCLK25_TRDY2_M3UDM_3), R90.2
DDR_UDMB: IC9.F2 (UDM), R90.1
DDR_UDQS: IC3.P2 (IO_L34P_M3UDQS_3), R88.2
DDR_UDQSB: IC9.E2 (UDQS), R88.1
GND: C60.2, C61.2, C62.2, C63.2, C64.2, C65.2, C66.2, C67.2, C68.2, C69.2, IC9.A1 (VSS), IC9.A3 (VSSQ), IC9.B9 (VSSQ), IC9.C1 (VSSQ), IC9.D9 (TEST), IC9.E1 (VSSQ), IC9.F1 (VSS), IC9.H7 (!CS), IC9.K1 (VSS), R71.1; also elsewhere on the board

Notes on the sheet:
1 Gbit
DDR
DDR should be 60-VFBGA (8x9) package for max flexibility and availability

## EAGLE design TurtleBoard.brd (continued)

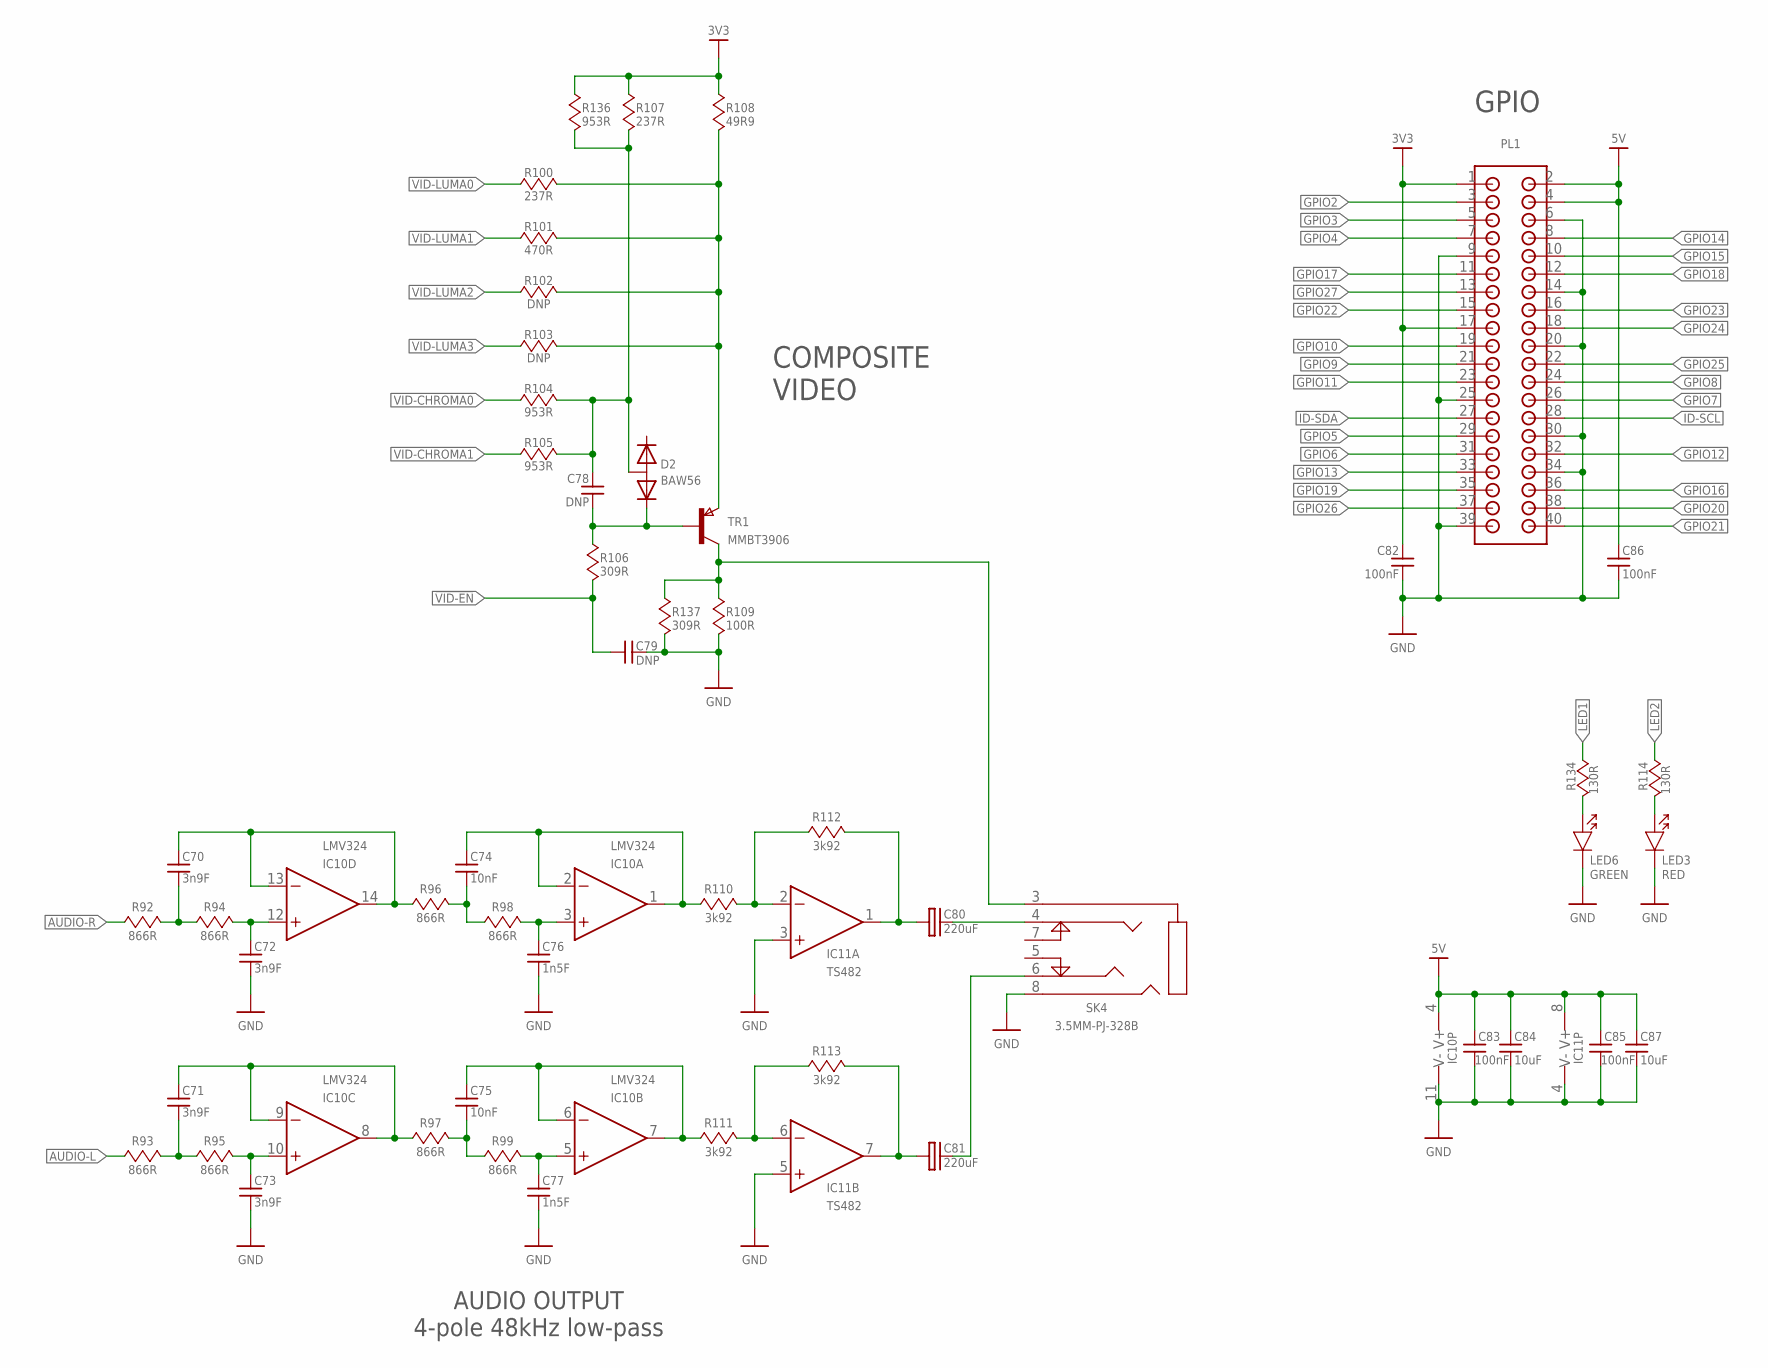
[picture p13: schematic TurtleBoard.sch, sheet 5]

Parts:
C70, C71, C72, C73: 3n9F; 0402
C74, C75: 10nF; 0402
C76, C77: 1n5F; 0402
C78, C79: DNP; 0402
C80, C81: 220uF; CP-6.3DIA
C82, C83, C85, C86: 100nF; 0402
C84, C87: 10uF; 0805
D2: BAW56; SC-75
IC10: LMV324; TSSOP14
IC11: TS482; MSOP08
LED3: RED; 0603-LED
LED6: GREEN; 0603-LED
PL1: 2X20-HEADER; 2X20_0.1"-HEADER
R92, R93, R94, R95, R96, R97, R98, R99: 866R; 0402
R100, R107: 237R; 0402
R101: 470R; 0402
R102, R103: DNP; 0402
R104, R105, R136: 953R; 0402
R106, R137: 309R; 0402
R108: 49R9; 0402
R109: 100R; 0402
R110, R111, R112, R113: 3k92; 0402
R114, R134: 130R; 0402
SK4: 3.5MM-PJ-328B
TR1: MMBT3906; SOT23

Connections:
3V3: C82.1, PL1.1, PL1.17, R107.2, R108.2, R136.2; also elsewhere on the board
5V: C83.2, C84.2, C85.2, C86.1, C87.2, IC10.4 (V+), IC11.8 (V+), PL1.2, PL1.4; also elsewhere on the board
!VID-EN: C79.1, R106.1; also elsewhere on the board
AUDIO-L: R93.1; also elsewhere on the board
AUDIO-R: R92.1; also elsewhere on the board
GND: C72.1, C73.1, C76.1, C77.1, C79.2, C82.2, C83.1, C84.1, C85.1, C86.2, C87.1, IC10.11 (V-), IC11.3 (+IN), IC11.4 (V-), IC11.5 (+IN), LED3.C, LED6.C, PL1.6, PL1.9, PL1.14, PL1.20, PL1.25, PL1.30, PL1.34, PL1.39, R109.1, R137.1, SK4.8; also elsewhere on the board
GPIO2: PL1.3; also elsewhere on the board
GPIO3: PL1.5; also elsewhere on the board
GPIO4: PL1.7; also elsewhere on the board
GPIO5: PL1.29; also elsewhere on the board
GPIO6: PL1.31; also elsewhere on the board
GPIO7: PL1.26; also elsewhere on the board
GPIO8: PL1.24; also elsewhere on the board
GPIO9: PL1.21; also elsewhere on the board
GPIO10: PL1.19; also elsewhere on the board
GPIO11: PL1.23; also elsewhere on the board
GPIO12: PL1.32; also elsewhere on the board
GPIO13: PL1.33; also elsewhere on the board
GPIO14: PL1.8; also elsewhere on the board
GPIO15: PL1.10; also elsewhere on the board
GPIO16: PL1.36; also elsewhere on the board
GPIO17: PL1.11; also elsewhere on the board
GPIO18: PL1.12; also elsewhere on the board
GPIO19: PL1.35; also elsewhere on the board
GPIO20: PL1.38; also elsewhere on the board
GPIO21: PL1.40; also elsewhere on the board
GPIO22: PL1.15; also elsewhere on the board
GPIO23: PL1.16; also elsewhere on the board
GPIO24: PL1.18; also elsewhere on the board
GPIO25: PL1.22; also elsewhere on the board
GPIO26: PL1.37; also elsewhere on the board
GPIO27: PL1.13; also elsewhere on the board
ID-SCL: PL1.28; also elsewhere on the board
ID-SDA: PL1.27; also elsewhere on the board
LED1: R134.2; also elsewhere on the board
LED2: R114.2; also elsewhere on the board
unnamed: IC11.2 (-IN), R110.2, R112.1
unnamed: C70.2, IC10.13 (-IN), IC10.14 (OUT), R96.1
unnamed: C70.1, R92.2, R94.1
unnamed: C72.2, IC10.12 (+IN), R94.2
unnamed: LED3.A, R114.1
unnamed: C80.- (MINUS), SK4.4
unnamed: C81.- (MINUS), SK4.6
unnamed: C78.1, D2.3 (A), R104.2, R105.2, R107.1, R136.1
unnamed: LED6.A, R134.1
unnamed: C78.2, D2.2 (K2), R106.2, TR1.1 (B)
unnamed: C74.2, IC10.1 (OUT), IC10.2 (-IN), R110.1
unnamed: C74.1, R96.2, R98.1
unnamed: C76.2, IC10.3 (+IN), R98.2
unnamed: C71.2, IC10.8 (OUT), IC10.9 (-IN), R97.1
unnamed: C80.+ (PLUS), IC11.1 (OUT), R112.2
unnamed: C71.1, R93.2, R95.1
unnamed: C73.2, IC10.10 (+IN), R95.2
unnamed: C75.2, IC10.6 (-IN), IC10.7 (OUT), R111.1
unnamed: C75.1, R97.2, R99.1
unnamed: C77.2, IC10.5 (+IN), R99.2
unnamed: IC11.6 (-IN), R111.2, R113.1
unnamed: C81.+ (PLUS), IC11.7 (OUT), R113.2
unnamed: R109.2, R137.2, SK4.3, TR1.3 (C)
unnamed: R100.2, R101.2, R102.2, R103.2, R108.1, TR1.2 (E)
VID-CHROMA0: R104.1; also elsewhere on the board
VID-CHROMA1: R105.1; also elsewhere on the board
VID-LUMA0: R100.1; also elsewhere on the board
VID-LUMA1: R101.1; also elsewhere on the board
VID-LUMA2: R102.1; also elsewhere on the board
VID-LUMA3: R103.1; also elsewhere on the board

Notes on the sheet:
GPIO
AUDIO OUTPUT 4-pole 48kHz low-pass
COMPOSITE VIDEO

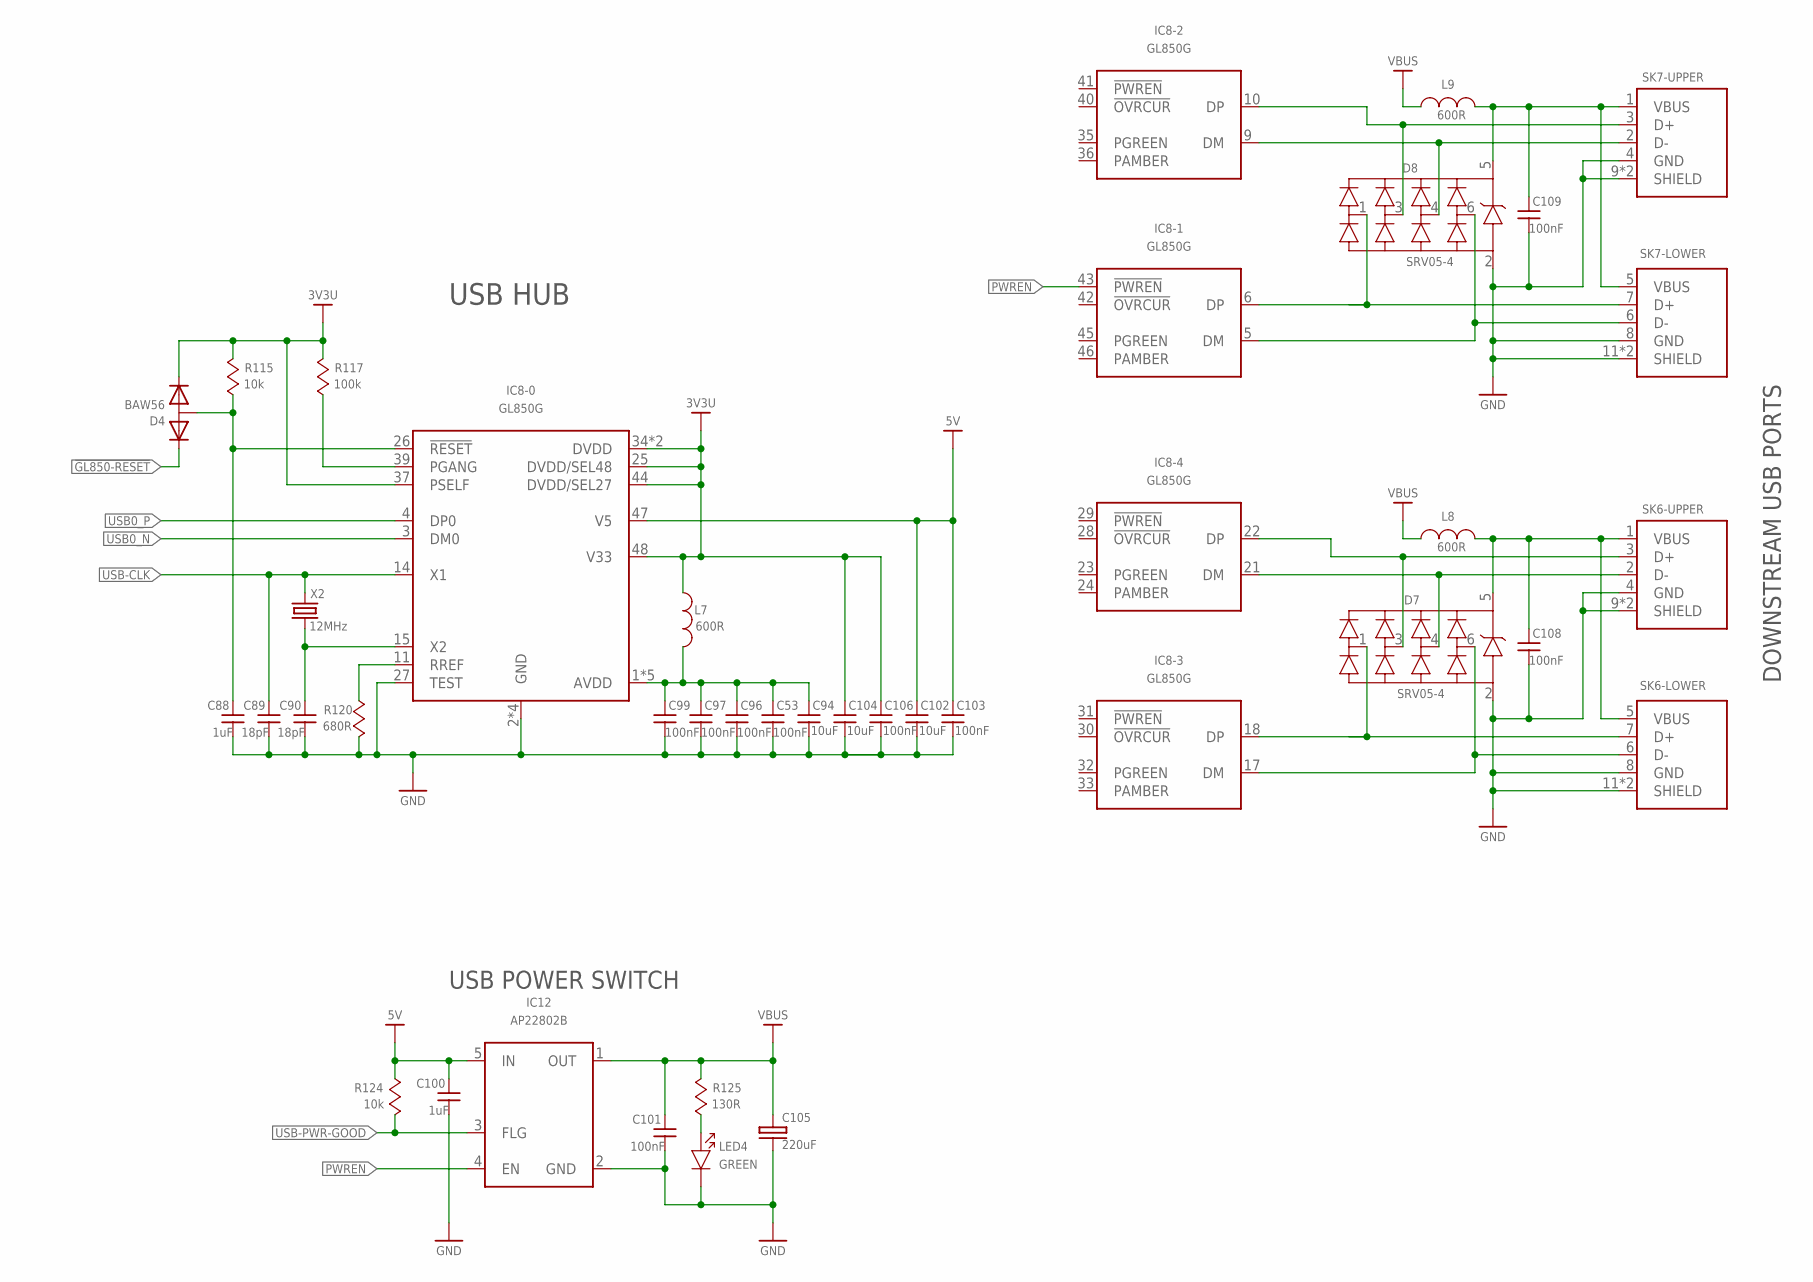
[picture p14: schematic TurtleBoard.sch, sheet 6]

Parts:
C53, C96, C97, C99, C101, C103, C106, C108, C109: 100nF; 0402
C88, C100: 1uF; 0402
C89, C90: 18pF; 0402
C94, C102, C104: 10uF; 0805
C105: 220uF; CP-6.3DIA
D4: BAW56; SC-75
D7, D8: SRV05-4; SOT23-6L
IC8: GL850G; LQFP48
IC12: AP22802B; SOT23-5
L7, L8, L9: 600R; C0805
LED4: GREEN; 0603-LED
R115, R124: 10k; 0402
R117: 100k; 0402
R120: 680R; 0402
R125: 130R; 0402
SK6, SK7: USB-A-DUAL
X2: 12MHz; XTAL-SMD-32X25

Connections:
3V3A: C53.2, C94.2, C96.2, C97.2, C99.2, IC8.1 (AVDD), IC8.7 (AVDD), IC8.12 (AVDD), IC8.16 (AVDD), IC8.19 (AVDD), L7.1
3V3U: C104.2, C106.2, D4.2 (K2), IC8.25 (DVDD/SEL48), IC8.34 (DVDD), IC8.37 (PSELF), IC8.38 (DVDD), IC8.44 (DVDD/SEL27), IC8.48 (V33), L7.2, R115.2, R117.2
5V: C100.2, C102.2, C103.2, IC8.47 (V5), IC12.5 (IN), R124.2; also elsewhere on the board
!GL850-RESET: D4.1 (K1); also elsewhere on the board
GND: C53.1, C88.1, C89.1, C90.1, C94.1, C96.1, C97.1, C99.1, C100.1, C101.1, C102.1, C103.1, C104.1, C105.- (MINUS), C106.1, C108.1, C109.1, D7.2 (-), D8.2 (-), IC8.2 (GND), IC8.8 (GND), IC8.13 (GND), IC8.20 (GND), IC8.27 (TEST), IC12.2 (GND), LED4.C, R120.1, SK6.4 (GND), SK6.8 (GND), SK6.9 (SHIELD), SK6.10 (SHIELD), SK6.11 (SHIELD), SK6.12 (SHIELD), SK7.4 (GND), SK7.8 (GND), SK7.9 (SHIELD), SK7.10 (SHIELD), SK7.11 (SHIELD), SK7.12 (SHIELD); also elsewhere on the board
unnamed: IC8.11 (RREF), R120.2
unnamed: IC8.39 (PGANG), R117.1
unnamed: C88.2, D4.3 (A), IC8.26 (!RESET), R115.1
unnamed: C108.2, D7.5 (+), L8.2, SK6.1 (VBUS), SK6.5 (VBUS)
unnamed: C109.2, D8.5 (+), L9.2, SK7.1 (VBUS), SK7.5 (VBUS)
unnamed: LED4.A, R125.1
PWREN: IC8.43 (!PWREN), IC12.4 (EN)
USB0_N: IC8.3 (DM0); also elsewhere on the board
USB0_P: IC8.4 (DP0); also elsewhere on the board
USB1_N: D7.4 (D3), IC8.21 (DM), SK6.2 (D-)
USB1_P: D7.3 (D2), IC8.22 (DP), SK6.3 (D+)
USB2_N: D7.6 (D4), IC8.17 (DM), SK6.6 (D-)
USB2_P: D7.1 (D1), IC8.18 (DP), SK6.7 (D+)
USB3_N: D8.4 (D3), IC8.9 (DM), SK7.2 (D-)
USB3_P: D8.3 (D2), IC8.10 (DP), SK7.3 (D+)
USB4_N: D8.6 (D4), IC8.5 (DM), SK7.6 (D-)
USB4_P: D8.1 (D1), IC8.6 (DP), SK7.7 (D+)
USB-CLK: C89.2, IC8.14 (X1), X2.3 (2); also elsewhere on the board
USB-CLK2: C90.2, IC8.15 (X2), X2.1
USB-PWR-GOOD: IC12.3 (FLG), R124.1; also elsewhere on the board
VBUS: C101.2, C105.+ (PLUS), IC12.1 (OUT), L8.1, L9.1, R125.2

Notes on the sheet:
USB HUB
DOWNSTREAM USB PORTS
USB POWER SWITCH

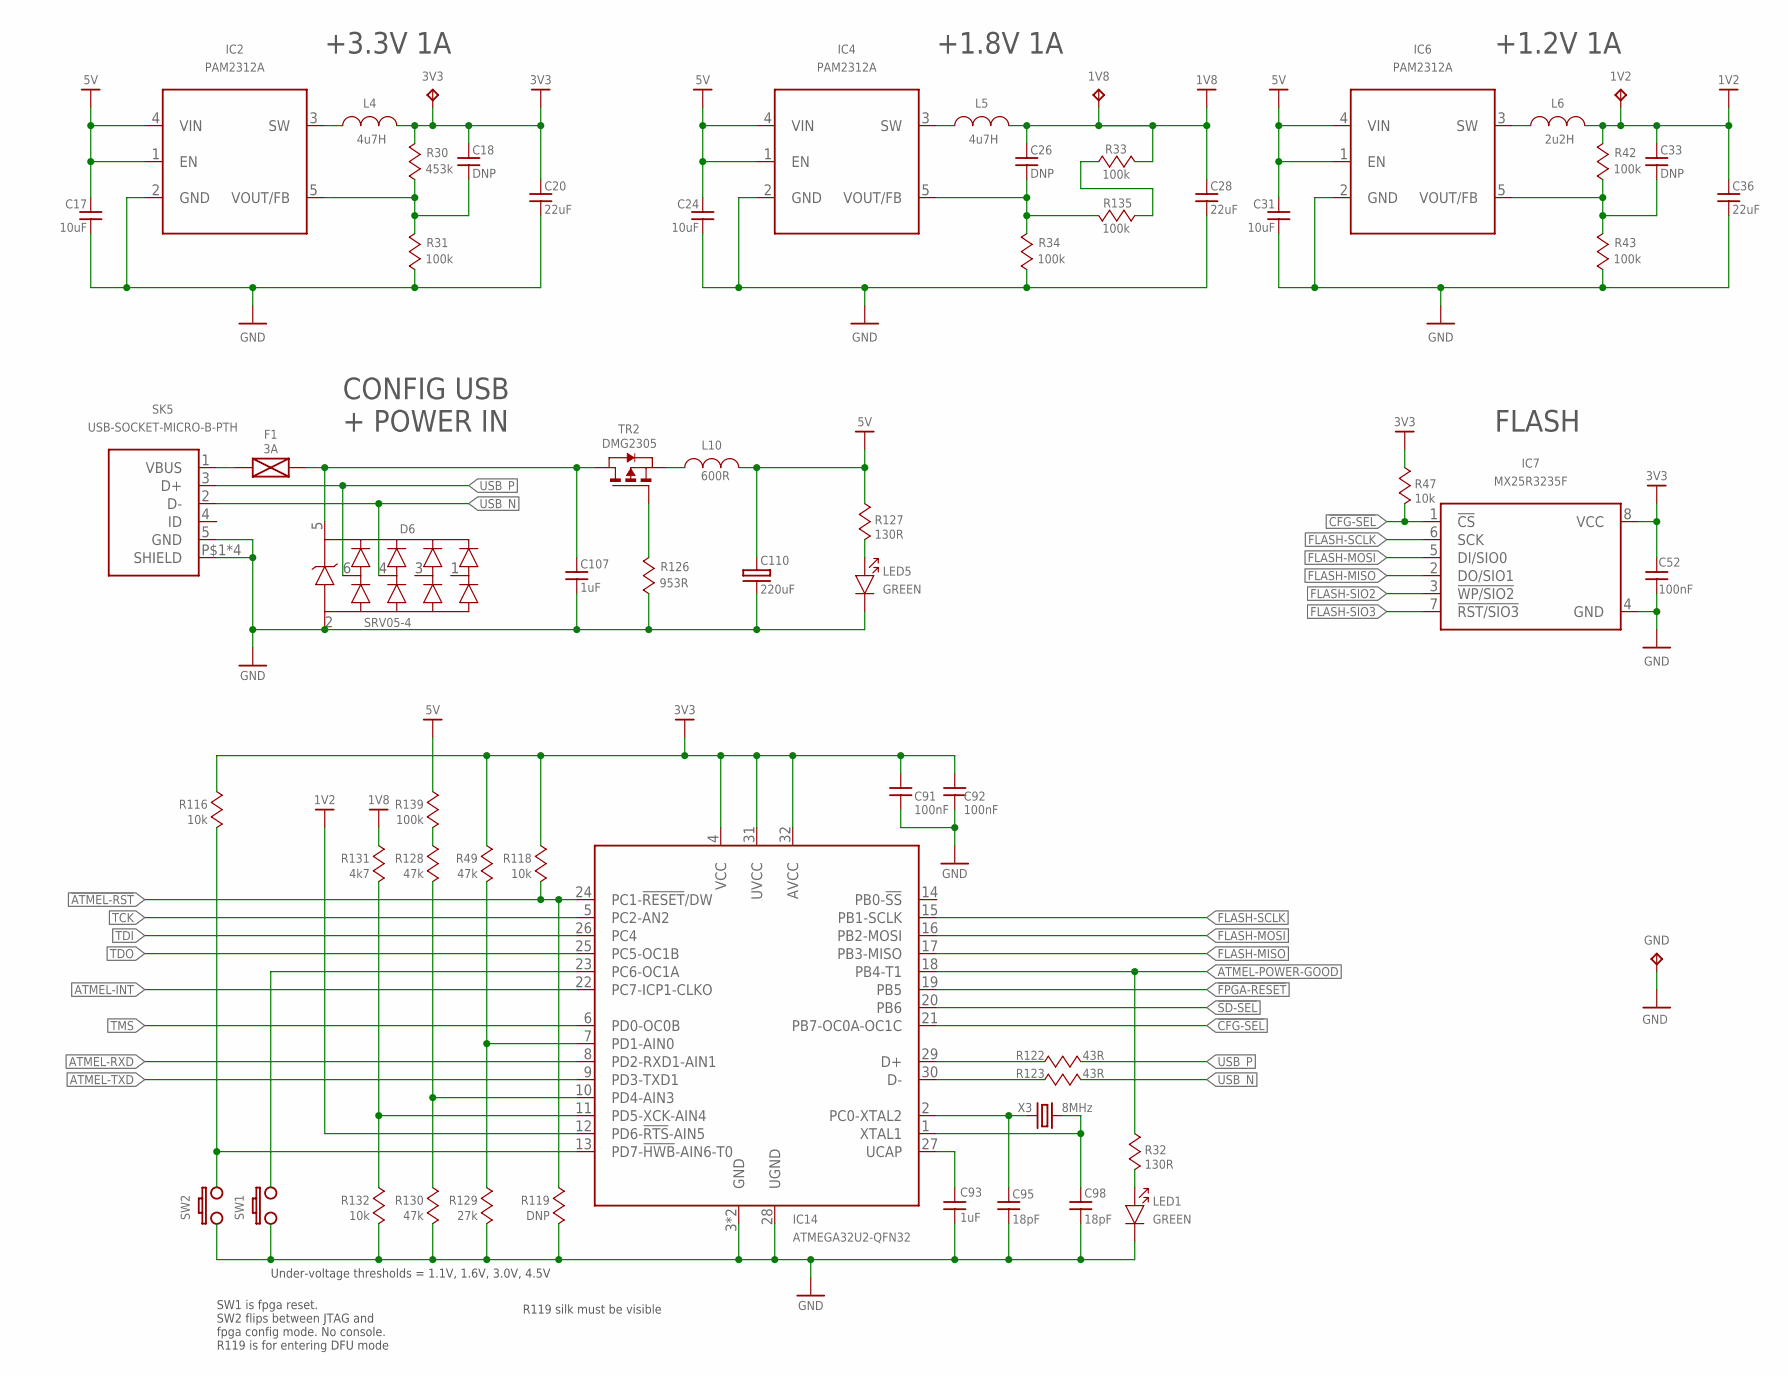
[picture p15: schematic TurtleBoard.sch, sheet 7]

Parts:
C17, C24, C31: 10uF; 0805
C18, C26, C33: DNP; 0402
C20, C28, C36: 22uF; 0805
C52, C91, C92: 100nF; 0402
C93, C107: 1uF; 0402
C95, C98: 18pF; 0402
C110: 220uF; CP-6.3DIA
D6: SRV05-4; SOT23-6L
F1: 3A; C1812
IC2, IC4, IC6: PAM2312A; TSOT23-5
IC7: MX25R3235F; SOIJ-8
IC14: ATMEGA32U2-QFN32; QFN-32
L4, L5: 4u7H; SRN6045
L6: 2u2H; SRN6045
L10: 600R; C1210
LED1, LED5: GREEN; 0603-LED
R30: 453k; 0402
R31, R33, R34, R42, R43, R135, R139: 100k; 0402
R32, R127: 130R; 0402
R47, R116, R118, R132: 10k; 0402
R49, R128, R130: 47k; 0402
R119: DNP; 0603
R122, R123: 43R; 0402
R126: 953R; 0402
R129: 27k; 0402
R131: 4k7; 0402
SK5: USB-SOCKET-MICRO-B-PTH; USB-MICRO-B-PTH
SW1, SW2: SWITCH-SPSTTACT-6X3; TACT-6X3
TP1: 3V3; P1-10
TP2: 1V8; P1-10
TP3: GND; P1-10
TP4: 1V2; P1-10
TR2: DMG2305; SOT23
X3: 8MHz; CRYSTAL-ABM3

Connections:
1V2: C33.1, C36.2, IC14.12 (PD6-!RTS!-AIN5), L6.2, R42.2, TP4.1; also elsewhere on the board
1V8: C26.1, C28.2, L5.2, R33.2, R131.2, TP2.1; also elsewhere on the board
3V3: C18.1, C20.2, C91.2, C92.2, IC14.4 (VCC), IC14.31 (UVCC), IC14.32 (AVCC), L4.2, R30.2, R47.2, R49.2, R116.2, R118.2, TP1.1; also elsewhere on the board
5V: C17.2, C24.2, C31.2, C110.+ (PLUS), IC2.1 (EN), IC2.4 (VIN), IC4.1 (EN), IC4.4 (VIN), IC6.1 (EN), IC6.4 (VIN), L10.2, R127.2, R139.2; also elsewhere on the board
!ATMEL-RST: IC14.24 (PC1-!RESET!/DW), R118.1, R119.2; also elsewhere on the board
!CFG-SEL: IC7.1 (!CS), IC14.21 (PB7-OC0A-OC1C), R47.1; also elsewhere on the board
!FPGA-RESET: IC14.19 (PB5); also elsewhere on the board
!SD-SEL: IC14.20 (PB6); also elsewhere on the board
ATMEL-INT: IC14.22 (PC7-ICP1-CLKO); also elsewhere on the board
ATMEL-POWER-GOOD: IC14.18 (PB4-T1), R32.2; also elsewhere on the board
ATMEL-RXD: IC14.8 (PD2-RXD1-AIN1); also elsewhere on the board
ATMEL-TXD: IC14.9 (PD3-TXD1); also elsewhere on the board
FLASH-MISO: IC7.2 (DO/SIO1), IC14.17 (PB3-MISO); also elsewhere on the board
FLASH-MOSI: IC7.5 (DI/SIO0), IC14.16 (PB2-MOSI); also elsewhere on the board
FLASH-SCLK: IC7.6 (SCK), IC14.15 (PB1-SCLK); also elsewhere on the board
FLASH-SIO2: IC7.3 (!WP/SIO2); also elsewhere on the board
FLASH-SIO3: IC7.7 (!RST/SIO3); also elsewhere on the board
GND: C17.1, C20.1, C24.1, C28.1, C31.1, C36.1, C52.1, C91.1, C92.1, C93.1, C95.1, C98.1, C107.2, C110.- (MINUS), D6.2 (-), IC2.2 (GND), IC4.2 (GND), IC6.2 (GND), IC7.4 (GND), IC14.3 (GND), IC14.28 (UGND), IC14.P (GND), LED1.C, LED5.C, R31.1, R34.1, R43.1, R119.1, R126.1, R129.1, R130.1, R132.1, SK5.5 (GND), SK5.P$1 (SHIELD), SK5.P$2 (SHIELD), SK5.P$3 (SHIELD), SK5.P$4 (SHIELD), SW1.P$2 (2), SW2.P$2 (2), TP3.1; also elsewhere on the board
unnamed: LED1.A, R32.1
unnamed: C93.2, IC14.27 (UCAP)
unnamed: IC14.29 (D+), R122.1
unnamed: IC14.30 (D-), R123.1
unnamed: C107.1, D6.5 (+), F1.1, TR2.3 (D)
unnamed: F1.2, SK5.1 (VBUS)
unnamed: IC2.3 (SW), L4.1
unnamed: IC6.3 (SW), L6.1
unnamed: C33.2, IC6.5 (VOUT/FB), R42.1, R43.2
unnamed: C18.2, IC2.5 (VOUT/FB), R30.1, R31.2
unnamed: R126.2, TR2.1 (G)
unnamed: LED5.A, R127.1
unnamed: IC14.13 (PD7-!HWB!-AIN6-T0), R116.1, SW2.P$1 (1)
unnamed: C98.2, IC14.1 (XTAL1), X3.2
unnamed: C95.2, IC14.2 (PC0-XTAL2), X3.1
unnamed: IC14.10 (PD4-AIN3), R128.1, R130.2
unnamed: R33.1, R135.1
unnamed: IC4.3 (SW), L5.1
unnamed: C26.2, IC4.5 (VOUT/FB), R34.2, R135.2
unnamed: L10.1, TR2.2 (S)
unnamed: IC14.7 (PD1-AIN0), R49.1, R129.2
unnamed: IC14.23 (PC6-OC1A), SW1.P$1 (1)
unnamed: IC14.11 (PD5-XCK-AIN4), R131.1, R132.2
unnamed: R128.2, R139.1
TCK: IC14.5 (PC2-AN2); also elsewhere on the board
TDI: IC14.26 (PC4); also elsewhere on the board
TDO: IC14.25 (PC5-OC1B); also elsewhere on the board
TMS: IC14.6 (PD0-OC0B); also elsewhere on the board
USB_N: D6.4 (D3), R123.2, SK5.2 (D-)
USB_P: D6.6 (D4), R122.2, SK5.3 (D+)
V: C52.2, IC7.8 (VCC)

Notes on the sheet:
SW1 is fpga reset. SW2 flips between JTAG and fpga config mode. No console. R119 is for entering DFU mode
Under-voltage thresholds = 1.1V, 1.6V, 3.0V, 4.5V
FLASH
+1.2V 1A
+3.3V 1A
+1.8V 1A
CONFIG USB + POWER IN
R119 silk must be visible

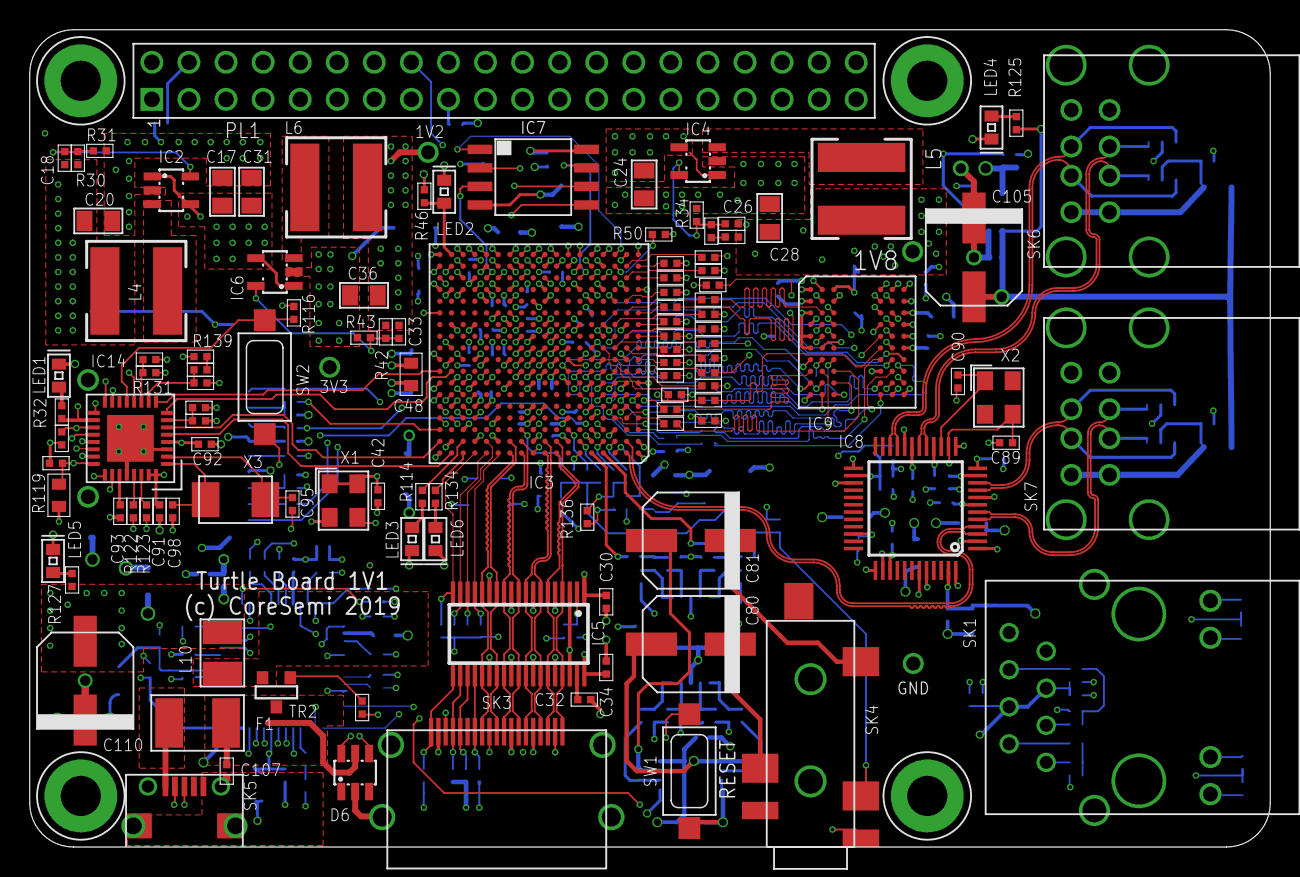
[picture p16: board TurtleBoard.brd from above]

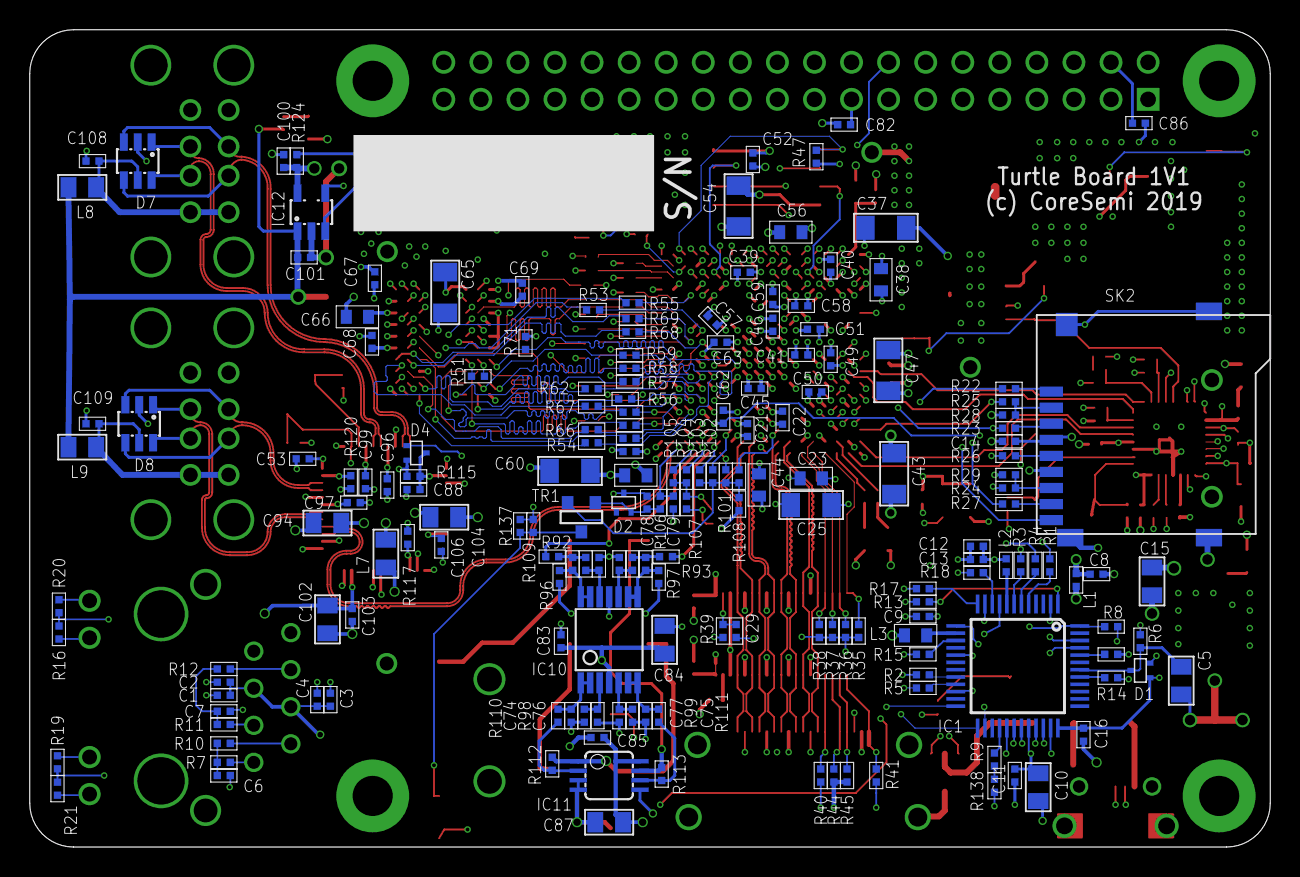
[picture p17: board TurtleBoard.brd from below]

Board: 8 copper layers, 85.0 x 56.0 mm, 303 parts (182 on the bottom side), 288 nets.

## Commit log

2020-05-18 SEI 2016 1v0 platform board
    [TurtleBoard.brd, TurtleBoard.sch]
2020-05-18 Schematic and top silk pdf files
2020-05-18 schamtic 1v1 board, as built
2020-06-21 v1.1 As built, Q3 2019
    [TurtleBoard.brd, TurtleBoard.sch]
